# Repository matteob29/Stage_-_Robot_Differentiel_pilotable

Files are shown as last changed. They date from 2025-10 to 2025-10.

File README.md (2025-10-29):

# Stage - Robot Différentiel pilotable

Projet réalisé dans le cadre du **Stage de Première année**

**Ateliers destinés aux stagiaires de seconde**  
**ENSEIRB-MATMECA – CEA** 

**Auteurs :**  
Mattéo BINET  
Bastien TRAN-RUESCHE 

**Encadrant :**  
Thierry TARIS

**Date :** Juin 2025  

---

## Présentation générale

Cet atelier a été conçu dans le cadre du partenariat entre **l’ENSEIRB-MATMECA** et le **CEA**, dans le but d’initier des élèves de seconde aux bases de la robotique.  
Il s’est déroulé à **EirLab**, le fablab de l’enseirb, sur des séances de trois heures encadrées par des étudiants de première année.

L’objectif était de faire découvrir la démarche complète de conception d’un système embarqué à travers la réalisation d’un **robot différentiel pilotable**.  
L’atelier combine ainsi trois volets :  
1. la **découverte du robot et de ses composants** ;  
2. la **fabrication partielle du châssis** et l’assemblage ;  
3. la **programmation du comportement autonome** du robot.

---

## Le robot

<p align="center">
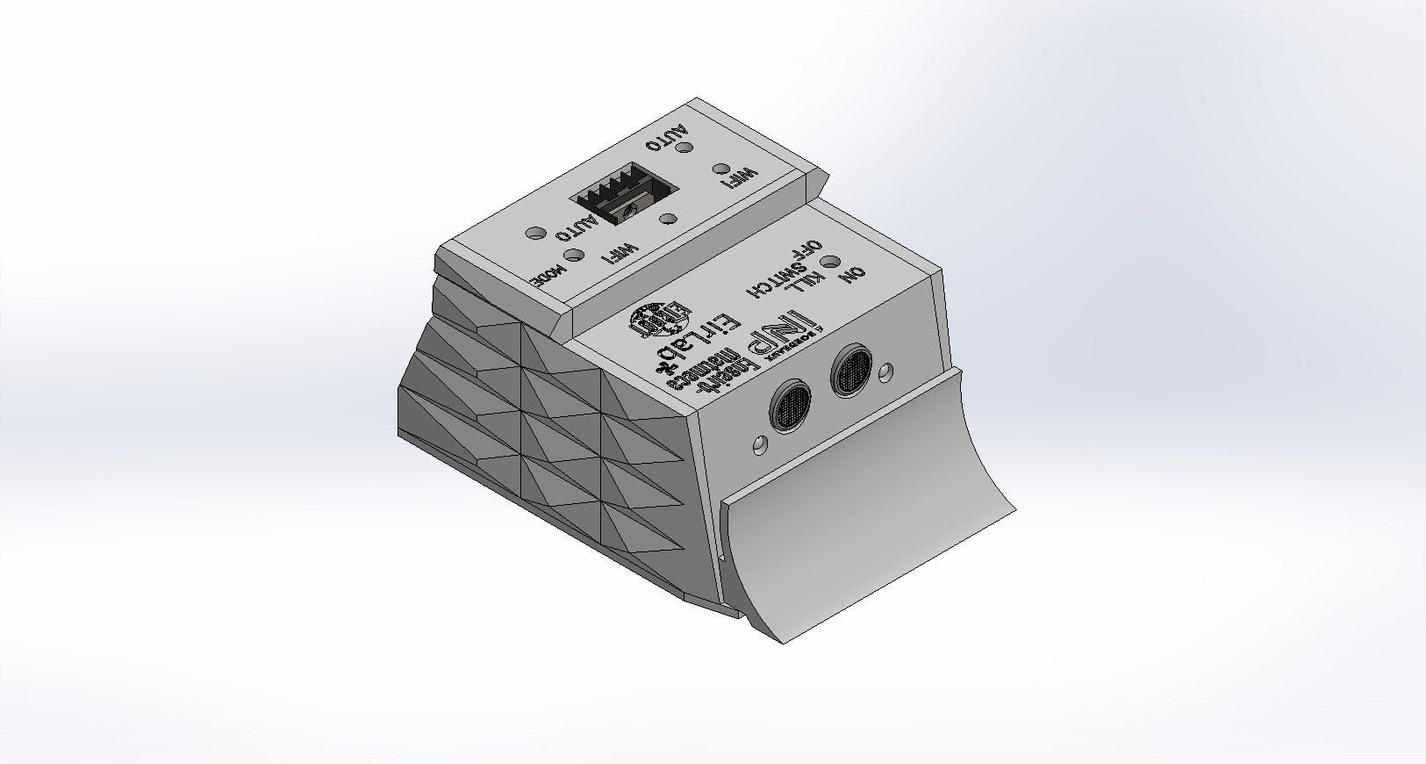
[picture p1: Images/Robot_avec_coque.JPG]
Robot avec coque
  
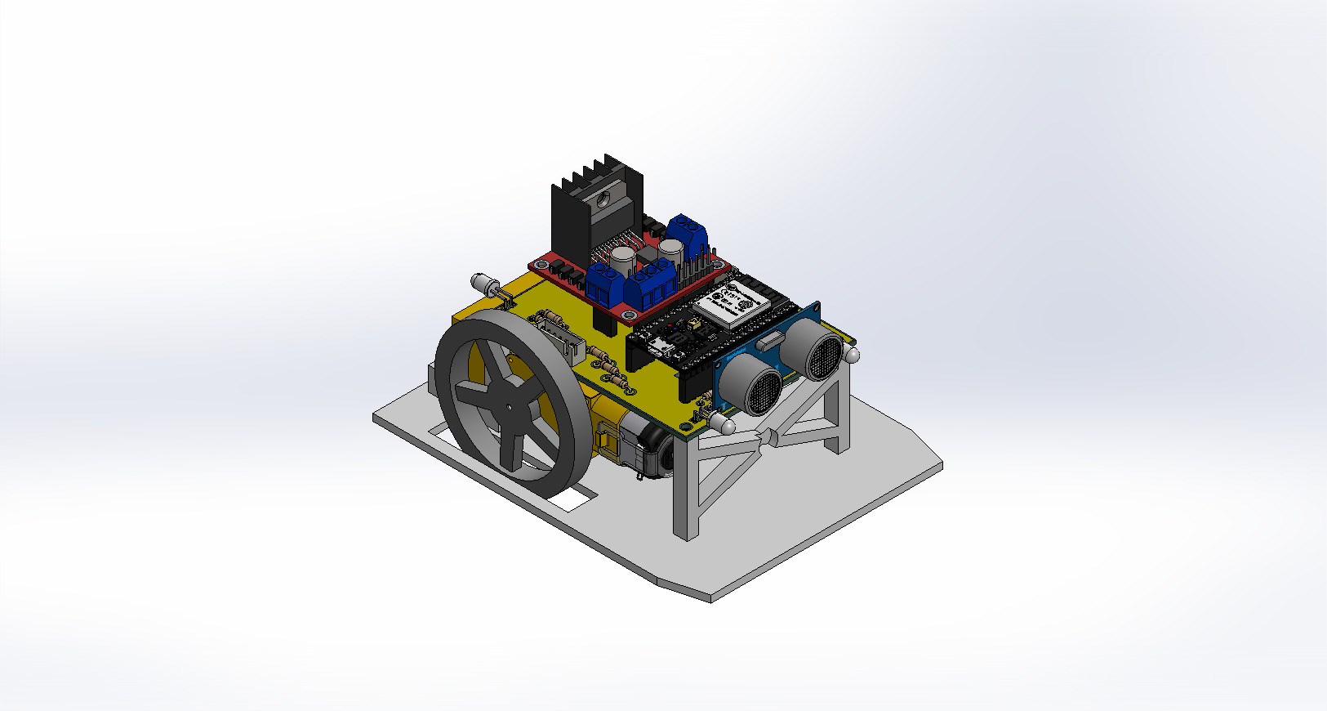
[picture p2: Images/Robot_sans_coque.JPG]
Robot sans coque
  
</p>

Le robot conçu est un **modèle différentiel** à deux roues motrices et une roue folle.  
Chaque moteur est commandé indépendamment à l’aide d’un **driver L298**, piloté par un **microcontrôleur ESP32** programmé dans l’environnement Arduino.  
L’ensemble est relié par une **carte d’interconnexion** assurant la distribution de l’alimentation et des signaux de commande.

Les principaux éléments du système sont :
- ESP32 (microcontrôleur)  
- Driver moteur L298  
- Deux moteurs à courant continu  
- Capteur à ultrasons  
- LEDs et interrupteurs  
- Batterie d’alimentation  

Le robot peut se déplacer, s’arrêter en fonction de la détection d’obstacles et être commandé à distance via une interface sans fil.

---

## Déroulement de l’atelier

L’atelier débute par une présentation du principe du robot différentiel et de ses composants électroniques.  
Les élèves réalisent ensuite la **plaque inférieure du châssis** à l’aide d’une **découpeuse laser**, puis procèdent à l’assemblage mécanique et à la soudure des moteurs.

La seconde partie est consacrée à la **programmation**.  
À partir d’un code partiellement fourni, les élèves complètent la logique du comportement autonome du robot à l’aide de fonctions simples issues d’une bibliothèque dédiée (`pami_lib.h`).

Exemples de fonctions utilisées :
- `avancer()`, `reculer()`, `stop()` : contrôle du déplacement  
- `mesurerDistance()` : lecture du capteur à ultrasons  
- `bluetoothControl()` : pilotage sans fil  

L’objectif final est d’obtenir un robot capable d’avancer, de s’arrêter en présence d’un obstacle et, en bonus, d’effectuer une manœuvre d’évitement.

---

## Objectifs pédagogiques

- Introduire les bases de la **robotique mobile** et des systèmes embarqués.  
- Apprendre à **assembler** et **câbler** un système électronique simple.  
- Découvrir la **programmation en C/Arduino** appliquée au pilotage de moteurs.  
- Développer des compétences de **rigueur, logique et travail collaboratif**.  

---

## Conclusion

Cet atelier illustre de manière concrète le processus complet de conception d’un système robotique :  
de la modélisation mécanique à la programmation, en passant par l’assemblage électronique.  
Il permet aux élèves de seconde d’aborder de façon pratique les disciplines de l’ingénierie et de découvrir le fonctionnement d’un robot autonome.

---

## Contenu du dépôt GitHub

Le dépôt [Stage - Robot Différentiel pilotable](https://github.com/matteob29/Stage_-_Robot_Differentiel_pilotable) contient les éléments suivants :

- [Codes/](./Codes)                        → Programmes ESP32 avec les controlles Wifi ou manette de PS4
- [Datasheets/](./Datasheets)                → Datasheet des coomposants utilisés
- [Images/](./Images)                      → Illustrations, photos et rendus du robot
- [Meca/](./Meca)                          → Modèles 3D et plans mécaniques (SolidWorks, SVG)
- [PCB/](./PCB)                            → Layouts et typons
- [Rapports/](./Rapports)                    → Rapports de stage et documents de présentation
- [README.md](./README.md)
  
---

© 2025 — Mattéo BINET, Bastien TRAN-RUESCHE  
Département Électronique — Stage 1ère année  
Enseirb-Matmeca — Robot Différentiel pilotable

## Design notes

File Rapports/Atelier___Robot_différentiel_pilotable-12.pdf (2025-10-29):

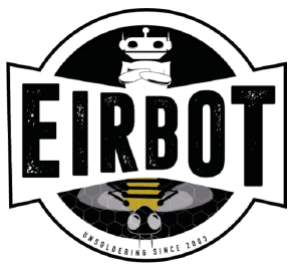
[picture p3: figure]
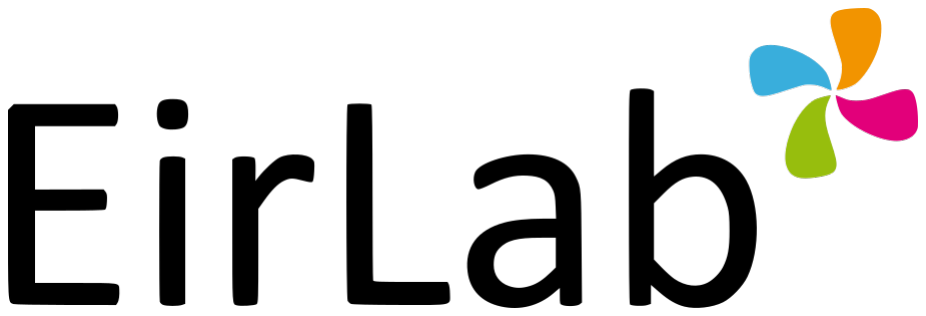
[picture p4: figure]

# Atelier - Conception d’un robot différentiel pilotable

Ateliers destinés aux stagiaires de seconde ENSEIRB-MATMECA - CEA

### Juin 2025

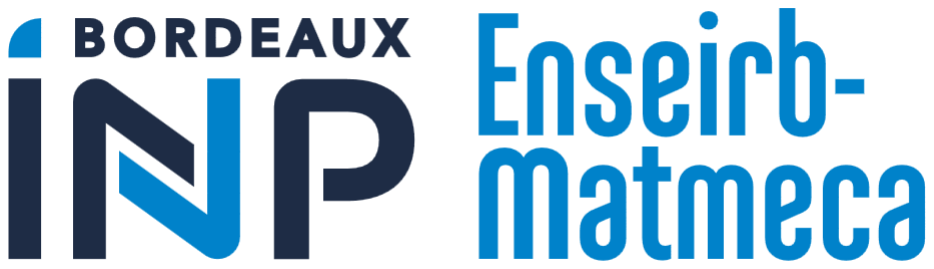
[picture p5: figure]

Auteurs :
Mattéo BINET
Bastien TRAN-RUESCHE

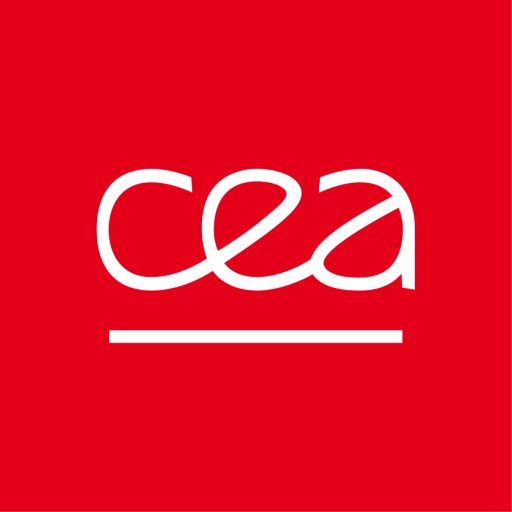
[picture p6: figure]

Tuteur :
Thierry TARIS

## Sommaire

1 Description de l’atelier | 4
2 Présentation du robot | 4
3 Partie Mécanique | 7
4 Partie Programmation | 9

2

Atelier - Conception d’un robot différentiel pilotable

## 1 Description de l’atelier

### 1.1 Format

L’atelier se déroule à EirLab (ENSEIRB-MATMECA) et dure 3 heures. Il se découpe en trois parties :
1. Présentation du robot à réaliser
2. Fabrication d’une partie du châssis à la découpeuse laser
3. Programmation du microcontrôleur

### 1.2 Cahier des charges

L’objectif de cet atelier est l’introduction à la robotique. Pour cela, les élèves de seconde participeront à plusieurs étapes de fabrication du robot. Pour gagner du temps, certaines pièces du châssis seront déjà découpées, la carte d’interconnexion préassemblée et le programme partiellement préparé.
Après la présentation du robot et de son fonctionnement, l’élève sera sollicité pour dessiner et découper la plaque de support du robot, pour assembler ce dernier (soudure et montage), ainsi que pour écrire la partie du programme correspondant au comportement « autonome » du robot.
Ainsi, un robot fonctionnel doit pouvoir être obtenu à la fin de l’atelier.

## 2 Présentation du robot

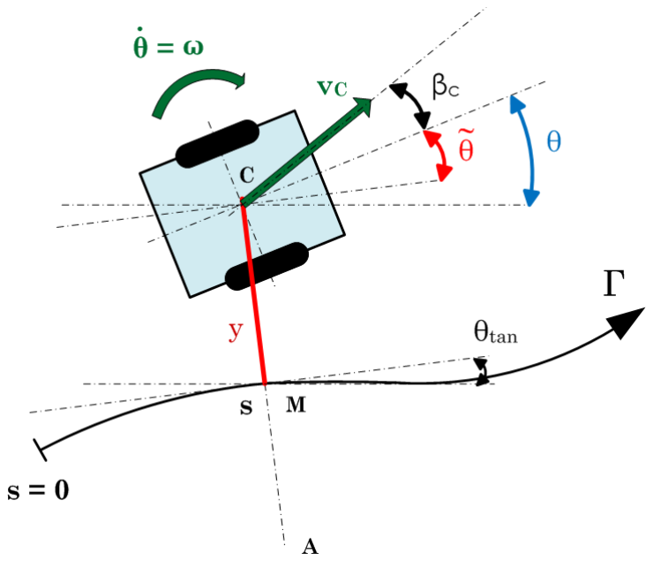
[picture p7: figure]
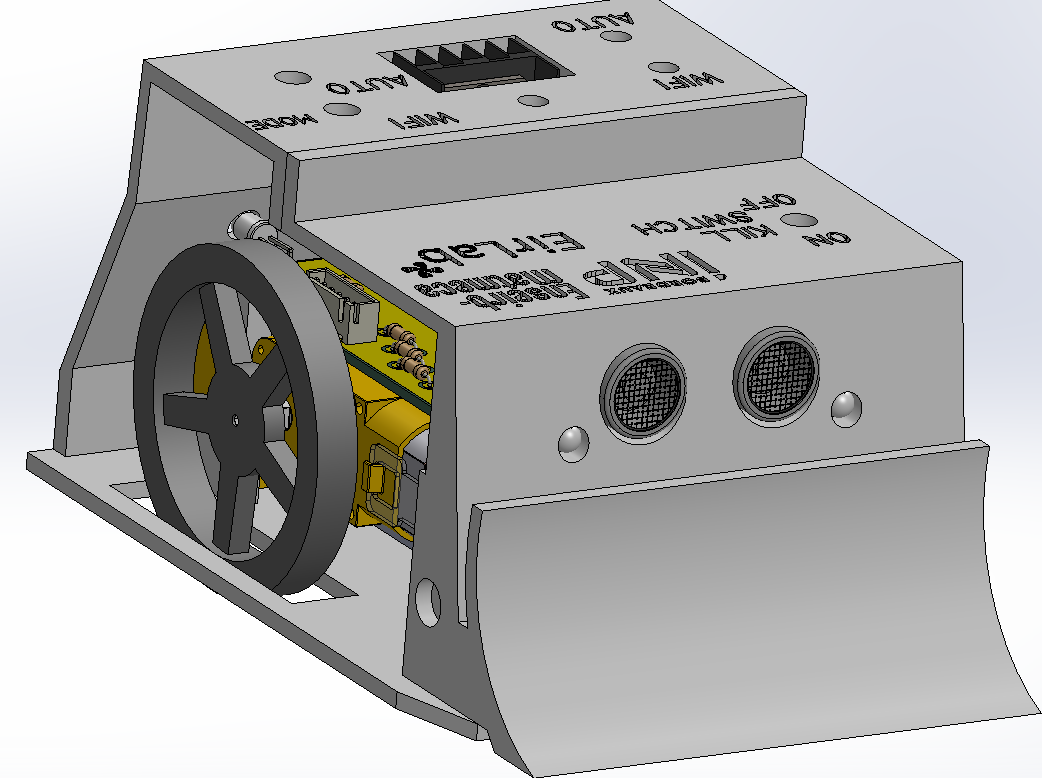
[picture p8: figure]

Le robot possède deux roues. Chaque roue est entraînée par un moteur que l’on peut contrôler de manière indépendante. Un tel robot peut effectuer plusieurs mouvements distincts :
1. Si les deux roues tournent dans le même sens et à la même vitesse, le robot va tout droit,
2. Si une des deux roues tourne plus vite, le robot tourne un peu,
3. Si les deux roues n’ont pas le même sens de rotation, le robot tourne sur lui-même.
Mattéo BINET | 4 | Bastien TRAN-RUESCHE

Cela veut dire que pour faire se mouvoir le robot comme on le veut, il faut contrôler le sens et la vitesse de la rotation de chaque moteur.

Le contrôle des moteurs est réalisé à l’aide : d’un microcontrôleur et d’un driver de moteur.

### 2.1 Les moteurs DC

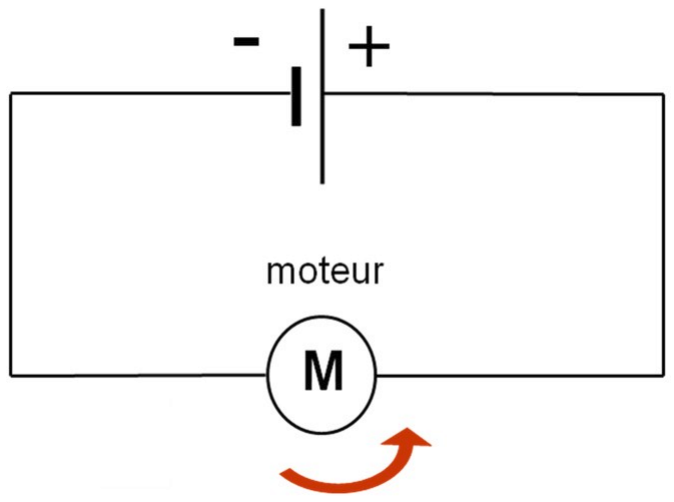
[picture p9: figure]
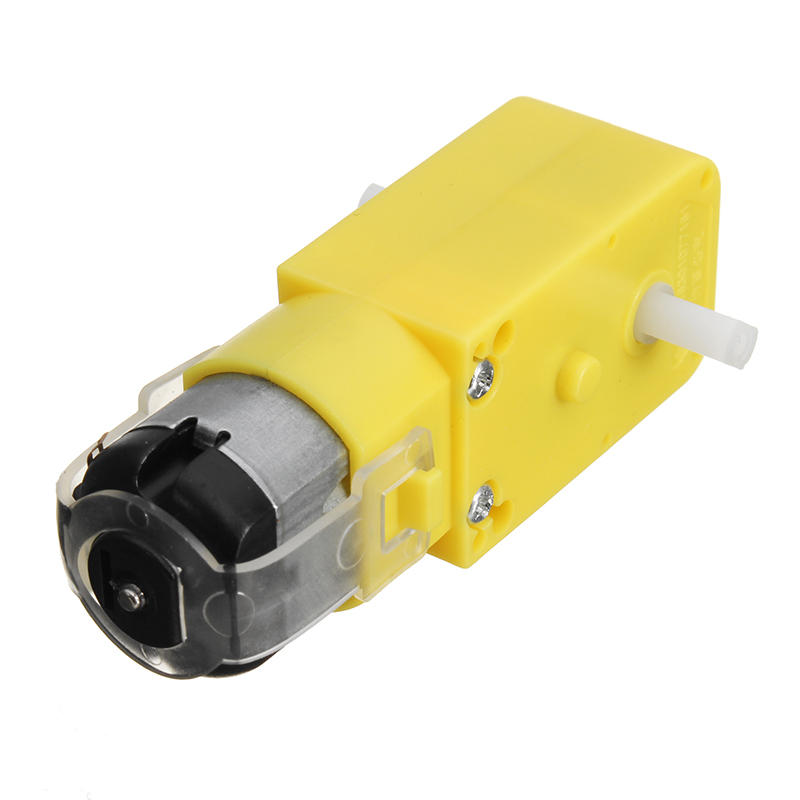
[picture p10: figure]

(a) Moteur DC | (b) Schéma électrique de branchement moteur

Direct Current = Courant Continu
Un moteur à courant continu est facilement contrôlable. Il suffit de le faire traverser par un courant (en appliquant une tension à ses bornes). En fonction de l’intensité et du sens du courant, il est possible de contrôler la vitesse et le sens de la rotation.

### 2.2 Le driver du moteur

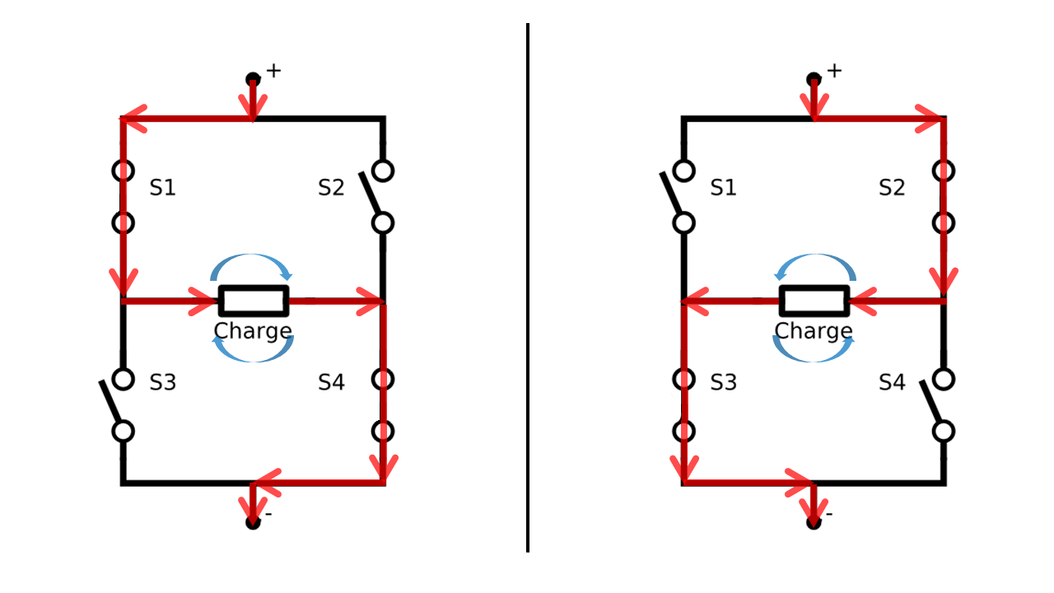
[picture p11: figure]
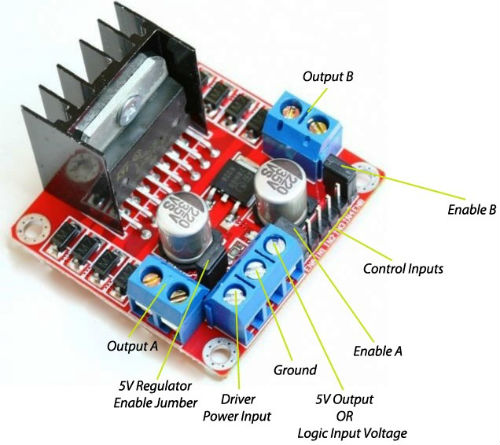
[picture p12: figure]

(a) Driver L298 | | (b) Schéma électrique du pont en H

Pour fournir la tension contrôlée aux moteurs (≈ 12V ), un composant de puissance est nécessaire car l’Arduino ne fournit pas une tension suffisante (≈ 5V ). Ce composant est appelé « driver » (peut se traduire par entraîneur).

La référence utilisée est le pont en H L298. Sans entrer dans les détails, il est commandé par un signal analogique donné par l’Arduino (entre 0 et 5V), et fournit aux moteurs une

Mattéo BINET | 5 | Bastien TRAN-RUESCHE

tension proportionnelle à ce signal.

Le driver permet ainsi de commander les moteurs de manière précise, mais avec puissance.

### 2.3 Le microcontrôleur (Arduino)

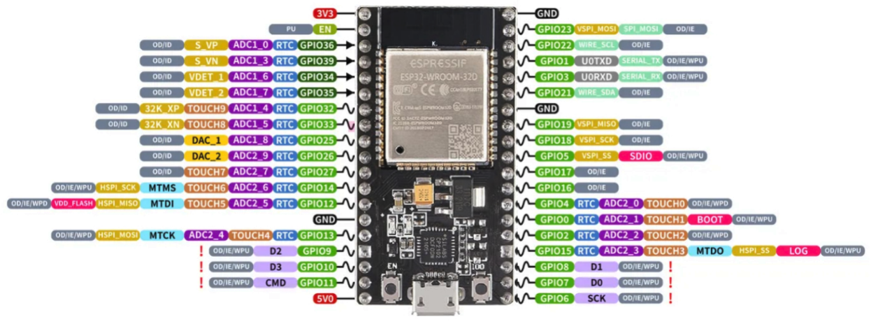
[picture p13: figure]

(a) Broches de l’ESP32

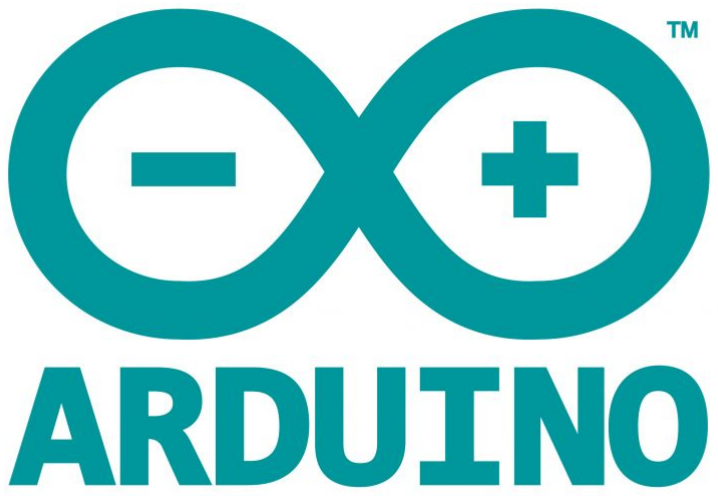
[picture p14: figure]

Un microcontrôleur est une carte programmable. En fonction du code qu’on lui donne, elle peut lire ou appliquer des tensions à ses bornes au cours du temps.

La carte utilisée est une ESP32, mais elle possède le même comportement qu’une carte Arduino (plus répandue et plus documentée).
Son rôle dans le robot est :
1. La mesure des entrées comme les boutons, le capteur à ultrasons...
2. Le choix des actions à réaliser en fonction de l’état des entrées
3. L’application des signaux de contrôle à ses sorties, vers le driver et les lumières par exemple.
Toutes ces étapes doivent être rigoureusement définies dans le programme donné au préalable au microcontrôleur. Si on a l’impression que le robot est autonome, c’est parce que son code est bien réalisé.

### 2.4 La carte d’interconnexion

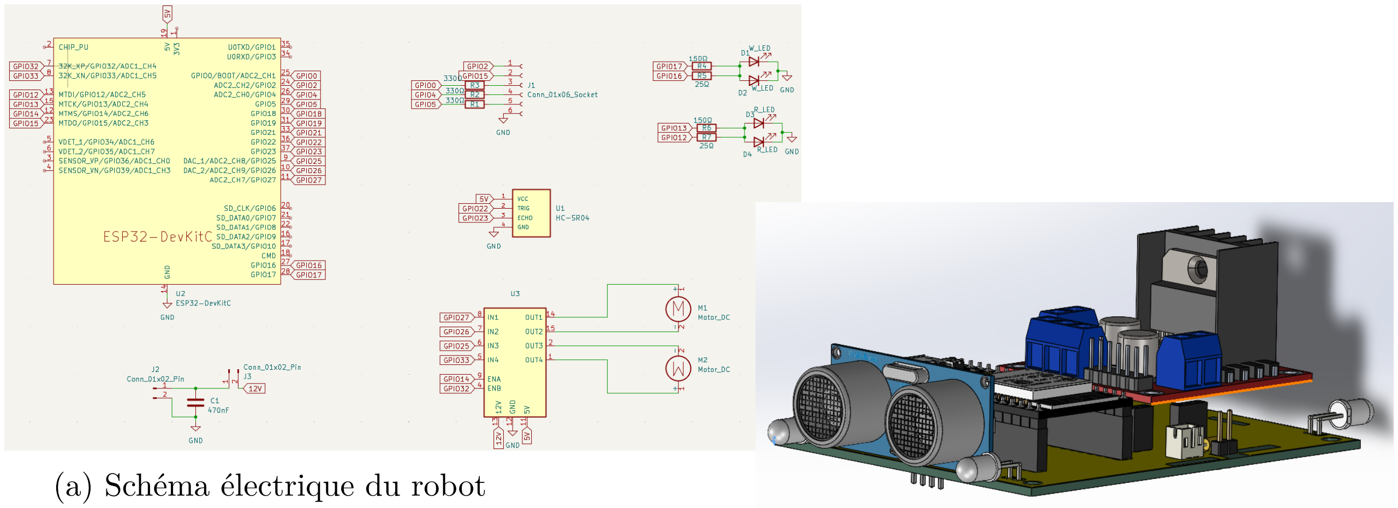
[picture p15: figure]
(a) Schéma électrique du robot

Mattéo BINET | 6 | Bastien TRAN-RUESCHE

Pour ce projet, une carte électronique a été préparée. Elle sert à relier les différents composants entre eux. Par exemple, six broches de l’ESP32 sont reliées aux six entrées de contrôle du driver. De manière similaire, l’alimentation 5V est partagée entre le capteur à ultrasons, la carte Arduino et le driver...
Les composants électroniques du robot sont :
1. le microcontrôleur ESP32,
2. les interrupteurs (3),
3. les lumières (7),
4. le capteur à ultrasons,
5. le driver moteur,
6. les moteurs (2),
7. la prise pour la batterie

## 3 Partie Mécanique

### 3.1 Objectif

La partie mécanique doit permettre aux stagiaires de fabriquer une partie du châssis du robot (la plaque inférieure) et de souder les moteurs à la carte d’interconnexion. Ils seront aussi amenés à assembler certaines parties du robot.

### 3.2 Fabrication de la plaque

Le logiciel utilisé n’importe pas beaucoup. Le seul point important est que le dessin final doit pouvoir être obtenu au format .svg .
Le dessin de la carte se fait suivant les cotes suivantes :
Considérations lors du dessin :

— Ne déssiner que la moitiée de la plaque. L’autre moitée s’obtient par symétrie,
— Placer les trous d’un même élement (supports moteurs, supports carte, trous des roues...) les un par rapport aux autres
— Placer les différents éléments par rapport à une même référence. On peut choisir la ligne de derrière et une ligne du côté (il faut donc les placer en premier).
Mattéo BINET | 7 | Bastien TRAN-RUESCHE

### 3.3 Soudure

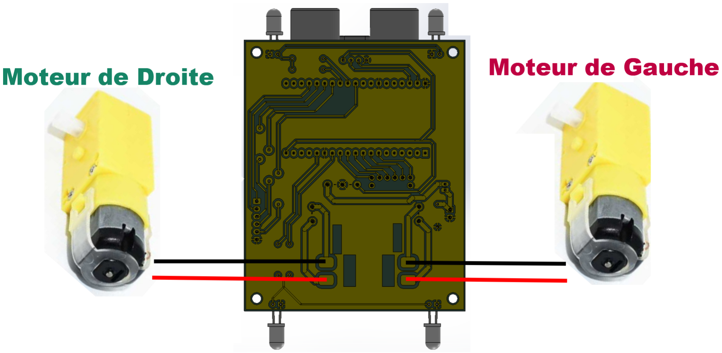
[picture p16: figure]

Figure 8 – Schéma de câblage des moteurs

Il faut relier les moteurs à la carte d’interconnexion. Chaque moteur possède deux fils : il y a donc 4 fils à souder sur la carte.

/!\ Pour la sécurité /!\ (gardez vos mains et vos yeux fonctionnels)

1. Porter des lunettes de sécurité
2. Souder sous supervision mais seul sur la table
3. Soit vous utilisez activement le fer, soit il est rangé dans son socle
4. Lors de la soudure, garder le fer loin des surfaces en plastiques et de votre autre main.
5. Les surfaces sont encore brulantes pendant plusieures minutes
6. Les troisièmes mains sont ajustables. Pas besoin de se mettre dans des positions incomfortables et dangeureuses.

Conseil pour une soudure de compétition :
— régler son fer entre 350° et 380°.
— nétoyr puis étamer son fer à chaque utilisation
— étamer les deux surfaces individuellement. Ensuite, réunir les deux surfaces ainsi que le fer. Il faut bien attendre que tout l’étain soit fondu avant d’enlever le fer. — L’étain ne se solidifie pas instantanément, il faut garder les surfaces à souder immobiles.
— Ne pas inverser + et - ; ne pas iverser moteur droit et moteur gauche.
Mattéo BINET | 8 | Bastien TRAN-RUESCHE

## 4 Partie Programmation

### 4.1 Objectif

L’objectif de la partie programmation est que le stagiaire programme le comportement autonome du robot.
La partie contrôle avec son téléphone à distance ainsi que les fonctions pour le déplacement du robot (avancer, aller à droite...) sont déjà programmées. Le stagiaire pourra les utiliser.

Des aides à la programmation sont aussi données plus loin dans le document.

### 4.2 Etapes de programmation

Dans cette partie, le stagiaire doit programmer le robot. Vu le temps accordé à l’atelier, une partie du code est déjà réalisée.

Documents fournis par les encadrants :
1. La librairie pami_lib.h du robot. On y trouve les fonctions pour faire bouger le robot comme avancer, reculer...
2. Le code main.c prérempli. L’import des librairies, la définition des pins et la fonction setup() sont déjà réalisés.

Travail demandé au stagiaire :
1. Réaliser la fonction loop(). Le comportement attendu est décrit ci-dessous dans les différentes étapes.

### 4.2.1 Étape 1 - Faire avancer le robot

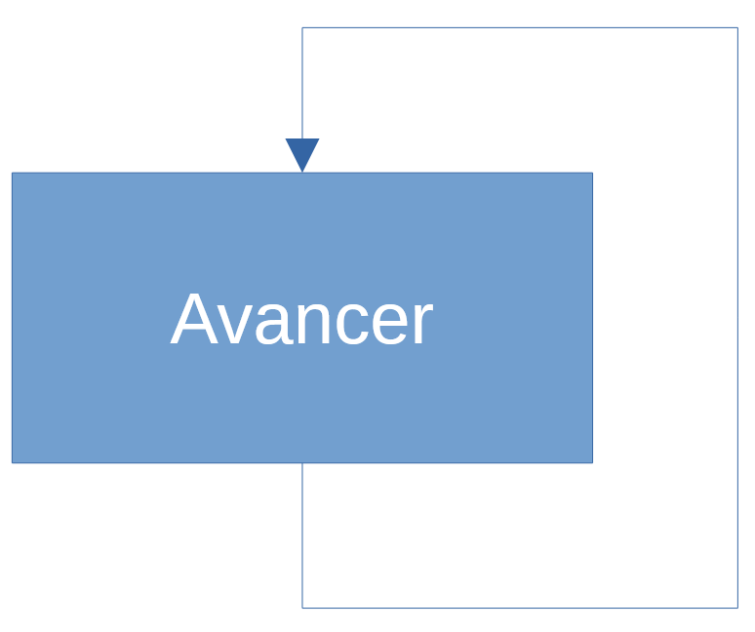
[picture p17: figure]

Pour faire avancer le robot, il faut appeler la fonction avancer(). On peut dire 3 choses sur cette fonction :
1. Elle est non bloquante. Son exécution est rapide et permet au programme de continuer à défiler. (contre-exemple : delay()).
2. Elle change l’état du robot. Tant qu’une instruction contraire n’est pas donnée, le robot continue à avancer.
3. L’appeler une seconde fois ne change rien.
À faire : Dans la loop(), écrire l’instruction avancer(); . Ensuite, téléverser.
Mattéo BINET | 9 | Bastien TRAN-RUESCHE

### 4.2.2 Étape 2 - Faire arrêter le robot

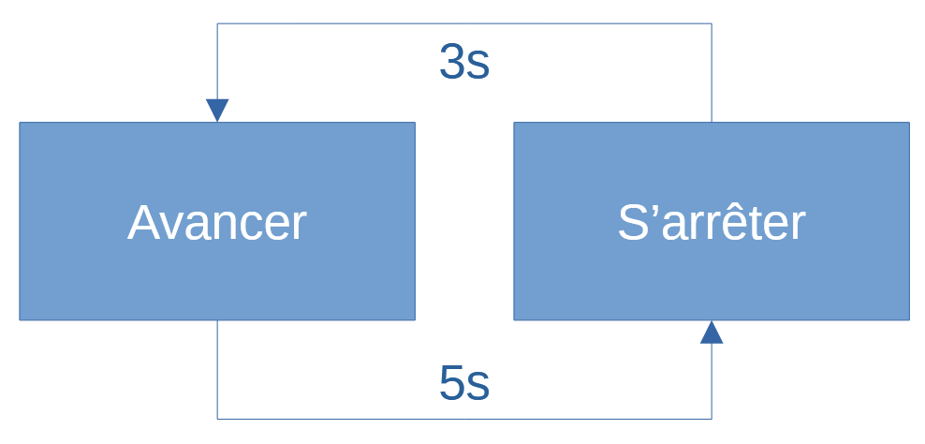
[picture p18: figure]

L’objectif est de faire avancer et arrêter le robot. La fonction d’attente est delay(). La fonction d’arrêt est stop().
Quelques précisions sur la fonction delay() :
1. Elle est bloquante. Son appel va stopper la lecture du programme pendant la durée spécifiée.
2. Aucun changement n’est effectué. Si le robot avance avant l’appel de delay(), il continuera d’avancer pendant toute la durée d’attente.

À faire : Modifier le programme pour que le robot : avance pendant 5 secondes, s’arrête pendant 3 secondes, et recommence en boucle...

### 4.2.3 Étape 3 - Utiliser le capteur à ultrasons

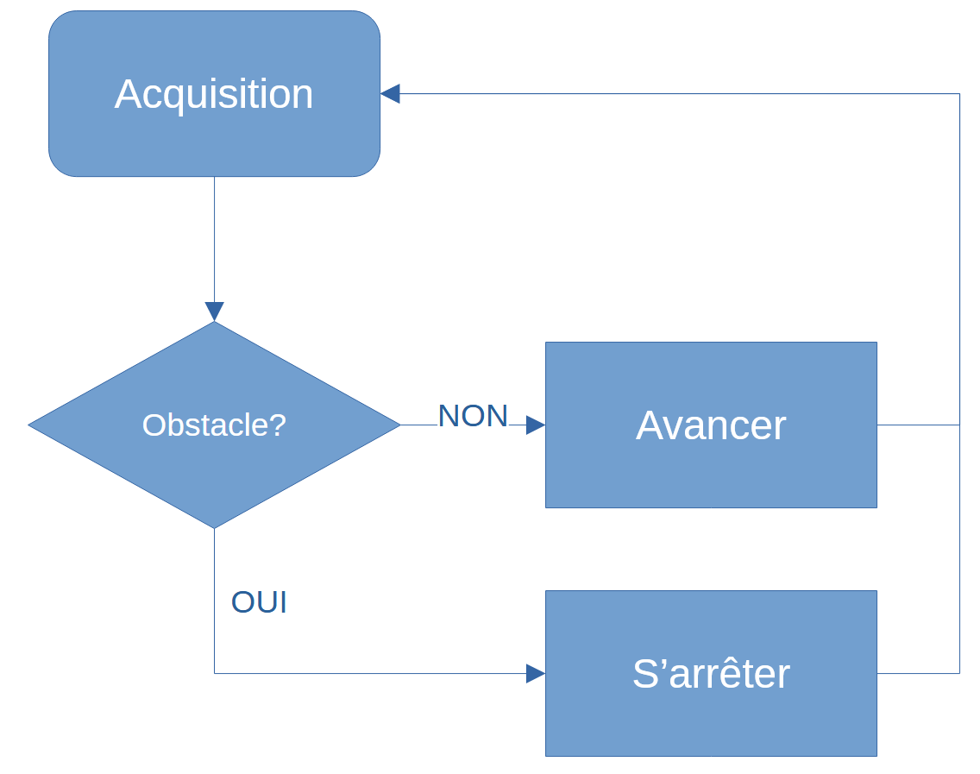
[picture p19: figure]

La fonction mesurerDistance() renvoie la distance en cm devant le capteur. On veut que le robot s’arrête quand il voit un obstacle devant lui. Il faut donc :
1. Récupérer la distance mesurée
2. La comparer à une valeur de référence (15 cm par exemple)
3. Choisir s’il faut avancer ou s’arrêter
À faire : Écrire dans la loop() un programme qui fait avancer le robot tant qu’un obstacle n’est pas détecté.
Mattéo BINET | 10 | Bastien TRAN-RUESCHE

### 4.2.4 Étape 4 - Manœuvre d’évitement (Bonus)

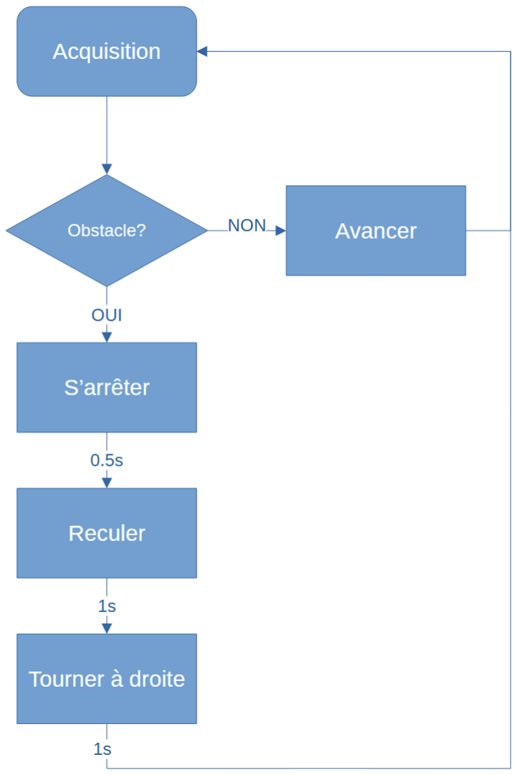
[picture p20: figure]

On propose maintenant en bonus d’effectuer une manœuvre d’évitement par le robot pour ne pas qu’il reste bloqué.

Bonus : Modifier le programme pour que le robot change de direction quand il détecte un obstacle.

### 4.3 Aides à la programmation

### 4.3.1 Variables et fonctions

— int a = 3; : entier
— float b = 3.14; : nombre décimal
— b = a + b; : modification de variable
— maFonction(3); : appel de fonction
— float c = maFonction(a); : affectation du résultat d’une fonction

/!\ Il faut mettre des points-virgules pour signaler la fin de l’instruction. Exemple :

int a = 3;

### 4.3.2 Conditions et boucles

Les tests : a == b, a < b, a <= b, a > b, a == HIGH...
Les boucles :

— if(condition){ instruction1; instruction2; ... } : si
— if(condition){ } else{ } : si ... sinon

— if(condition){ } else if(condition2){ } else{ } : si ... sinon si ... sinon

Mattéo BINET | 11 | Bastien TRAN-RUESCHE

— while(condition){ } : tant que

— for(initialisation; condition; incrment){ } : pour

### 4.3.3 Fonctions propres à Arduino

— setup() : fonction automatiquement appelée au démarrage de la carte — loop() : fonction automatiquement appelée en boucle
— pinMode(pin, mode); : fonction pour configurer une broche
— digitalRead(pin); : fonction pour lire la valeur d’une broche. Renvoie LOW ou HIGH — digitalWrite(pin, value); : fonction pour écrire LOW ou HIGH sur une broche

Les fonctions setup() et loop() sont appelées automatiquement par la carte Arduino. Elles doivent être définies par l’utilisateur avec le type void, car elles ne renvoient rien. Exemple : void setup(){ ... }. On utilise la même structure pour définir ses propres fonctions.
En revanche, les fonctions comme pinMode sont déjà définies ailleurs. L’utilisateur peut les appeler s’il le souhaite.
/!\ Il faut mettre des points-virgules pour signaler la fin de l’instruction. Exemple :

pinMode(12, INPUT);

### 4.3.4 Fonctions de la librairie PAMI

— beginPami(); : initialise le PAMI
— avancer(); : pour avancer
— reculer(); : pour reculer
— droite(); : le PAMI tourne sur lui-même (sens horaire)
— gauche(); : le PAMI tourne sur lui-même (sens antihoraire)
— stop(); : pour s’arrêter
— mesurerDistance(); : retourne la distance en cm mesurée par le capteur à ultrasons — bluetoothControl(); : actualise le comportement du robot en fonction des commandes Bluetooth

/!\ Il faut mettre des points-virgules pour signaler la fin de l’instruction. Exemple :

avancer();

### 4.3.5 Autres

— Attente en ms : delay(ms_a_attendre);

— Commentaire : // reste de la ligne en commentaire
— Inclure une librairie : #include "nomLibrairie.h"

— Macro : #define MA_MACRO 12

Mattéo BINET | 12 | Bastien TRAN-RUESCHE

### 4.3.6 Un exemple pour illustrer

Le programme suivant scrute l’interrupteur sur la broche 13. S’il est activé, alors c’est le capteur à ultrasons qui est scruté. Si la distance devant le capteur est supérieure à 15 cm, alors le robot avance. Si une des deux conditions n’est pas remplie, le robot est arrêté.

Listing 1 – Exemple C++

# include " pami_lib .h"

# define SWITCH_PIN 13

void setup () {
beginPami () ;
pinMode ( SWITCH_PIN , INPUT ) ;

}

void loop () {
if( digitalRead ( SWITCH_PIN ) == HIGH ) { int distance = mesurerDistance () ; if( distance >= 15) {
avancer () ;
} else {
stop () ;

}

}
else {
stop () ;

}

}

Mattéo BINET | 13 | Bastien TRAN-RUESCHE

E E

F F

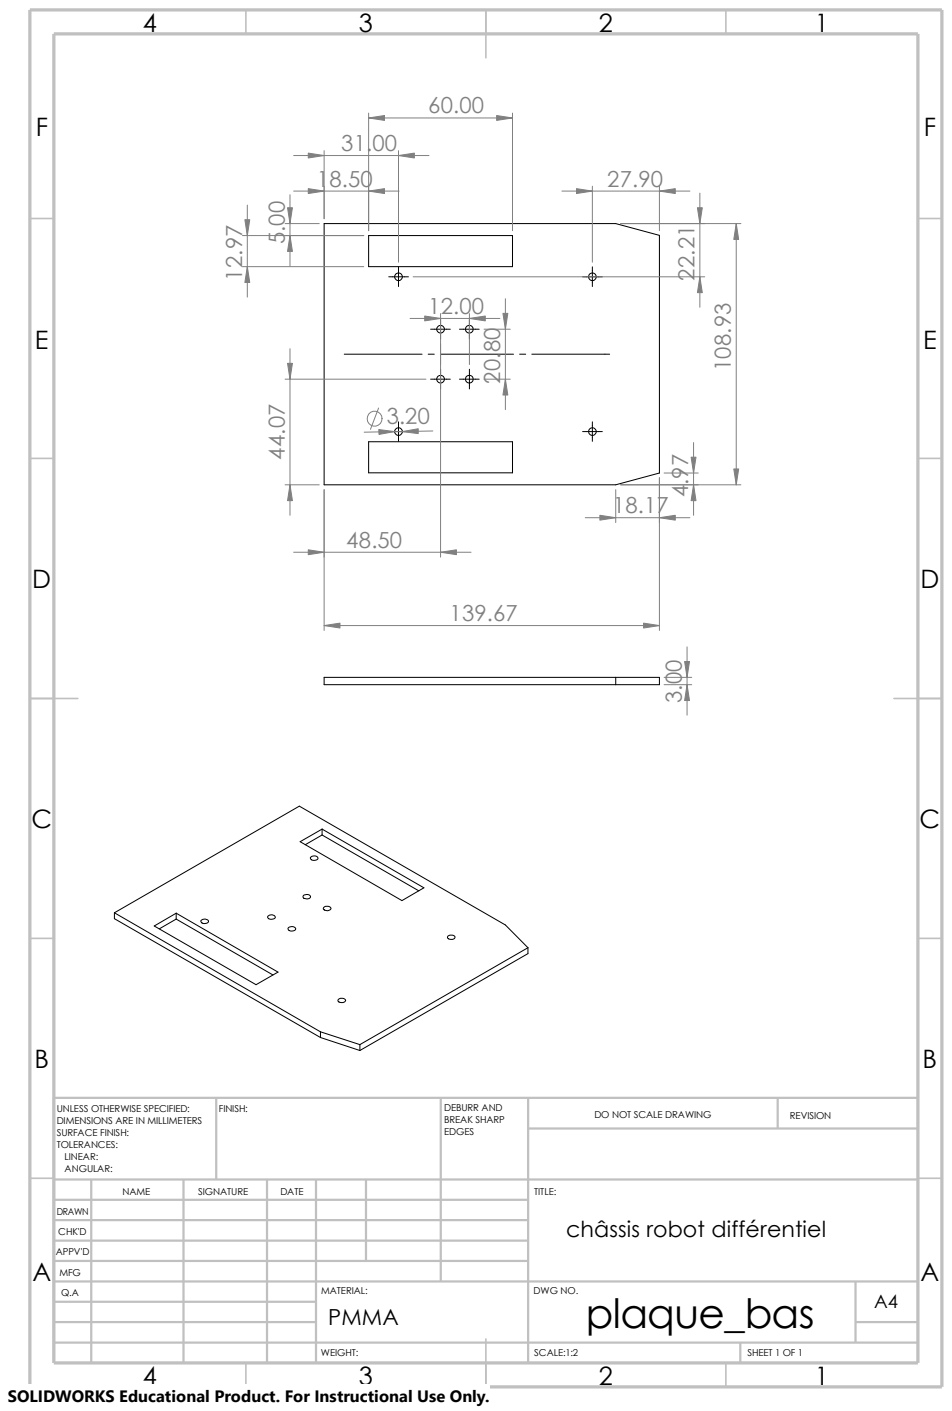
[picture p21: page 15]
DWG NO.; SCALE:1:2; TITLE:; WEIGHT:; SHEET 1 OF 1; DO NOT SCALE DRAWING; REVISION; MATERIAL:; SIGNATURE; DATE DRAWN; MFG; FINISH:; EDGES; NAME; DEBURR AND BREAK SHARP; plaque_bas ³.00; PMMA; châssis robot différentiel ¹⁰⁸.93 44.07

UNLESS OTHERWISE SPECIFIED:
DIMENSIONS ARE IN MILLIMETERS
SURFACE FINISH:
TOLERANCES:
LINEAR:
ANGULAR:

CHK'D
APPV'D

SOLIDWORKS Educational Product. For Instructional Use Only.

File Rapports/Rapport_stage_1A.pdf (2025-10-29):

# LE RÉCIT DES DÉCOUVERTES

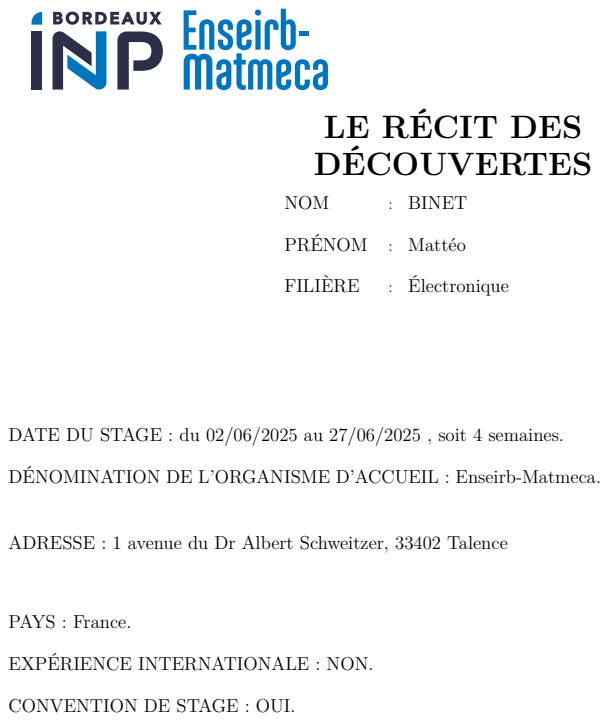
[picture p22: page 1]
NOM; : BINET; PRÉNOM; : Mattéo; FILIÈRE; : Électronique; PAYS : France.

DATE DU STAGE : du 02/06/2025 au 27/06/2025 , soit 4 semaines.

DÉNOMINATION DE L’ORGANISME D’ACCUEIL : Enseirb-Matmeca.

ADRESSE : 1 avenue du Dr Albert Schweitzer, 33402 Talence

EXPÉRIENCE INTERNATIONALE : NON.

CONVENTION DE STAGE : OUI.

## Sommaire

1 Introduction | 4
2 Récit de la découverte | 6

LE RÉCIT DES DÉCOUVERTES

## 1 Introduction

### 1.1 Choix du stage

Lorsque j’ai recherché un stage pour la fin de ma première année, je voulais une expérience en lien avec mes études d’électronique. Mon objectif était de mettre en pratique certaines notions abordées en cours, comme la réalisation de cartes électroniques, la programmation en C/C++ ou l’utilisation de microcontrôleurs.
J’espérais également pouvoir associer à ce travail certaines de mes passions personnelles, notamment la modélisation 3D. C’est ce qui m’a immédiatement attiré dans le projet de fabrication d’un petit robot : il combinait la conception d’un objet concret et la transmission de cette expérience à des lycéens dans un cadre pédagogique.
La durée du stage, fixée à quatre semaines, s’adaptait parfaitement à ce format, avec deux semaines consacrées à la réalisation du robot et deux autres à l’animation d’ateliers.

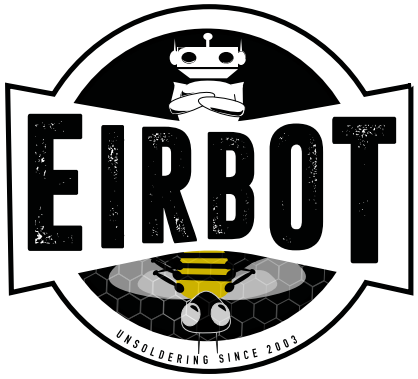
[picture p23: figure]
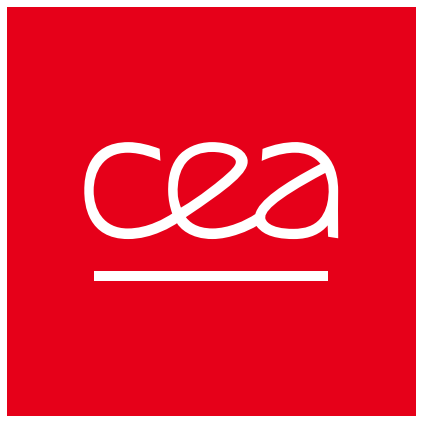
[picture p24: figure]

Figure 1 – Entités intervenantes dans le stage

Mattéo BINET | 4

### 1.2 Présentation du lieu de stage et du contexte

Mon stage s’est déroulé au sein d’EirLab, le fablab de l’ENSEIRB-MATMECA. Cet espace de 400 m² est dédié à la fabrication numérique et met à disposition des imprimantes 3D, une découpeuse laser, une fraiseuse CNC ainsi que du matériel électronique. L’école avait choisi de recruter des étudiants de première année pour préparer des ateliers destinés à des lycéens, en partenariat avec le CEA. Ce projet s’inscrivait pleinement dans l’esprit collaboratif d’EirLab.
J’ai participé à ce stage en tant que membre de l’association EirLab, aux côtés de mon binôme, M. Bastien Tran-Ruesche, de l’association de robotique EirBot. Notre mission était encadrée par M. Thierry Taris, ancien responsable de la filière Électronique, et accompagnée par les présidents des deux associations, M. Quentin Fallito (EirLab) et M. Romain Goudeau (EirBot).

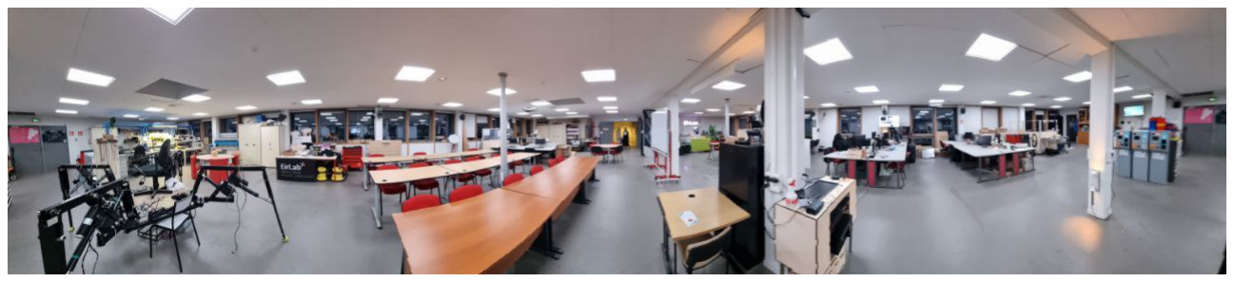
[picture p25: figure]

Figure 2 – Plateau ouvert d’EirLab

Au-delà du cadre immédiat de l’EirLab, ce stage s’inscrivait dans un dispositif plus large porté conjointement par l’ENSEIRB-MATMECA et le CEA. Ces deux institutions proposaient à des élèves de seconde une série d’ateliers de découverte scientifique et technique, couvrant des thématiques variées telles que la robotique, la bioélectronique, l’optique ou encore la cryptographie. Huit ateliers étaient organisés par notre école, chacun encadré par des groupes d’étudiants, tandis que onze autres, dont une visite du Laser Mégajoule, étaient proposés par le CEA. L’objectif de ce programme était de donner aux lycéens un premier aperçu concret de la diversité des métiers de l’ingénierie et de la recherche. C’est dans ce contexte que s’inscrivait notre stage : concevoir et préparer l’atelier de robotique, destiné à des binômes d’élèves de seconde, sur des sessions de trois heures.

## 2 Récit de la découverte

### 2.1 Création du robot

Les deux premières semaines du stage ont été consacrées à la préparation de l’atelier. En amont, une réunion a été organisée avec les stagiaires, notre tuteur et les présidents des associations afin de commencer à visualiser les grandes lignes du projet. Une seconde réunion, le premier jour de stage, a permis de définir plus précisément les objectifs à atteindre et de planifier le travail à réaliser pour que tout soit prêt à la troisième semaine. Il fallait absolument que le stage soit prêt pour les stagiaires de seconde.
Avec mon binôme, nous avons ensuite choisi les outils que nous allions utiliser : un logiciel de conception mécanique pour la modélisation en trois dimensions (SolidWorks), un autre pour la réalisation des circuits électroniques (Kicad), ainsi qu’un environnement de programmation pour écrire le code du robot (VSCode).
Nous avons également défini les composants nécessaires au projet, comme le microcontrôleur, les moteurs et leurs systèmes de commande. L’idée était de concevoir un robot simple à construire, mais qui puisse aussi servir de base à de futurs projets pour d’autres étudiants.
À titre d’exemple, une journée type durant cette période commençait à 9h et on débutait par se mettre d’accord pour répartir les tâches de la journée. L’un pouvait avancer sur la modélisation du châssis tandis que l’autre travaillait sur la préparation du circuit électronique. Puis à midi, nous allions manger au Restaurant Universitaire afin de faire une pause et de prendre du recule sur nos décisions de conception. Puis on reprenait vers 14h souvent sur une autre partie que celle faite le matin même. L’après-midi était généralement consacré à des essais pratiques et de la production de pièce (Carte électronique, découpe laser ou impression 3D).


Figure 3 – Modélisation du Robot sur SolidWorks avec coque


Figure 4 – Modélisation du Robot sur SolidWorks sans coque

Un autre travail essentiel a consisté à la fin de la deuxième semaine, à préparer le contenu du stage destiné aux lycéens. Plusieurs ateliers ont été retenus pour occuper une séance de trois heures : modéliser le châssis du robot, le découper et le graver au laser, souder les éléments électroniques, faire le montage du robot, puis programmer et tester le robot pour un mode de fonctionnement automatique. Afin de rendre l’expérience plus motivante, chaque élève pouvait personnaliser son châssis en y gravant une image de son choix, ce qui a donné lieu à des résultats variés et originaux. Enfin, une fois toutes ces étapes réalisées, les participants avaient la possibilité de piloter le robot à distance avec leur téléphone, grâce à la connexion sans fil (Wi-Fi).
Le point le plus délicat, au cours de cette préparation, a été d’évaluer les connaissances et la capacité d’attention de lycéens de seconde. Il fallait trouver un équilibre entre un contenu suffisamment intéressant et des activités accessibles à leur niveau. C’est pour cette raison que nous avons prévu plusieurs ateliers différents, afin d’éviter la répétition et de pouvoir alterner les rôles avec mon binôme.

### 2.2 Mise en œuvre des ateliers

Les deux dernières semaines du stage ont été consacrées à l’accueil et à l’encadrement des élèves de seconde. Chaque binôme disposait d’une séance de trois heures avec nous. Notre rôle était de guider les élèves à travers les différentes étapes en leur donnant des explications simples et adaptées à leur niveau. L’objectif était de leur permettre de comprendre les grandes lignes de la démarche tout en conservant un aspect concret et ludique. Lorsque nous devions expliquer un concept ou le fonctionnement d’un élément technique, il était souvent nécessaire de faire le lien avec quelque chose qu’ils connaissaient déjà et de simplifier au maximum les explications.
Un moment particulièrement apprécié fut la personnalisation du châssis grâce à la gravure laser, qui donnait lieu à des résultats variés et parfois très créatifs. Chaque élève repartait avec son propre châssis personnalisé : certains choisissaient une image du Laser Mégajoule, d’autres représentaient une vague en référence à un autre atelier suivi auparavant.
L’encadrement de ces ateliers représentait une expérience nouvelle et exigeante. Il fallait s’adapter au rythme de chaque binôme, répondre à des questions parfois complexe et gérer le temps de manière stricte afin que toutes les étapes puissent être réalisées dans la limite des trois heures. Avec mon binôme, nous nous relayions pour assurer un suivi attentif et maintenir l’intérêt des élèves tout au long de la séance.

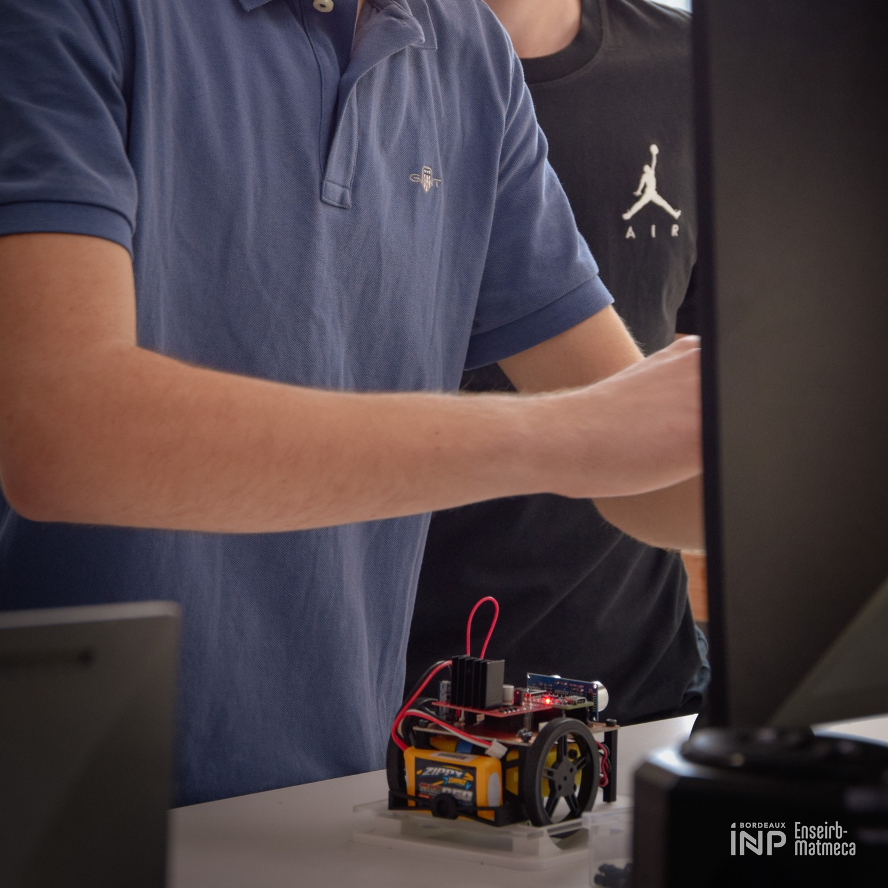
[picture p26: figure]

Figure 5 – Photos montrant le montage du robot et la conception du châssis.
Source : Instagram : enseirbmatmeca.bxinp

Ce qui m’a particulièrement marqué est la capacité des élèves à réussir les activités, même lorsqu’elles constituaient pour eux une découverte complète. Leur curiosité et leur envie d’apprendre leur permettaient de dépasser rapidement les premières difficultés, et ils prenaient visiblement plaisir à manipuler le matériel et à explorer de nouvelles notions. De mon côté, j’ai découvert l’importance d’adapter mon discours à un public plus jeune, en simplifiant le vocabulaire et en prenant le temps de reformuler lorsque cela était nécessaire. J’ai également mesuré à quel point la préparation en amont avait été déterminante : elle nous a permis de gérer les imprévus avec souplesse et d’assurer le bon déroulement des séances. Par exemple, lorsque la découpeuse laser était déjà utilisée, nous pouvions proposer immédiatement une autre activité, comme la soudure, et ainsi maintenir le rythme de l’atelier.
Cette expérience m’a donc apporté autant sur le plan technique que sur le plan humain, en développant ma capacité à transmettre, à encadrer et à m’adapter aux situations.

## Conclusion

Ce stage m’a permis de vivre une expérience riche et variée, à la fois technique et humaine. J’ai été marqué par l’équilibre entre la phase de préparation, où il fallait faire preuve de méthode et d’organisation, et la phase d’animation, où l’adaptation et la pédagogie étaient essentielles.
Parmi les aspects les plus marquants, je retiens la curiosité et l’enthousiasme des élèves, qui ont su réussir des activités nouvelles pour eux avec beaucoup d’implication. Leur motivation a rendu l’encadrement stimulant et gratifiant. J’ai également découvert l’importance de la simplification du discours et de la capacité à trouver des exemples concrets pour expliquer un concept complexe.
Certaines difficultés ont tout de même jalonné le stage, notamment la nécessité de gérer le temps limité des ateliers et de s’adapter aux imprévus techniques ou organisationnels. Toutefois, ces contraintes se sont révélées formatrices, car elles m’ont appris à faire preuve de souplesse et à maintenir un déroulement cohérent malgré les aléas.
En définitive, cette découverte a renforcé mon intérêt pour l’électronique et la robotique, tout en m’ouvrant à une dimension nouvelle : la transmission et l’encadrement. Elle m’a montré que le métier d’ingénieur ne se limite pas à des compétences techniques, mais implique aussi de savoir communiquer, accompagner et vulgariser son savoir. Cette expérience s’inscrit donc pleinement dans mon projet de formation, et constitue une étape précieuse dans mon parcours.

# ATTESTATION D’ACTIVITE

### Remettre l’original avec le rapport de stage

### Lieu et date : ___Pessac, 14/09/2025________________________________

### Ä Je soussigné (e) monsieur : TARIS Thierry

### Ä Atteste en qualité de : Directeur de Filière, Tuteur de stage tél :__________________________________

### : dénomination social: ENSEIRB Adresse

Ä Pour le compte de | l’organisme de formation
autre | Pays

### Ä Que (nom de l’étudiant (e)) : _________________________________________________________

Ä A (sélectionner la fonction) | - été stagiaire (convention de stage)

### - été employé(e) (contrat de travail) - été bénévole - suivi une formation (valable que pour les stages à l’étranger - autres (à indiquer) :

### A temps complet Ä Sur la période du _____________________au ________________________ Soit _______semaines

## SIGNATURE ET CACHET OBLIGATOIRE DE L’ENTREPRISE OU DE L’ORGANISME

## SIGNATURE DE L’ELEVE

(certifie exactes les informations ci-dessus)


Le responsable des stages ainsi que le directeur des études se réservent le droit de vérifier ces informations Eric.astien@bordeaux-inp.fr (responsable stage 1A)

# BINET Mattéo

02/06/2025 | 27/06/2025 | 4

### 1 avenue du Dr Albert Schweitzer

B.P. 99

### 33402 Talence Cedex France

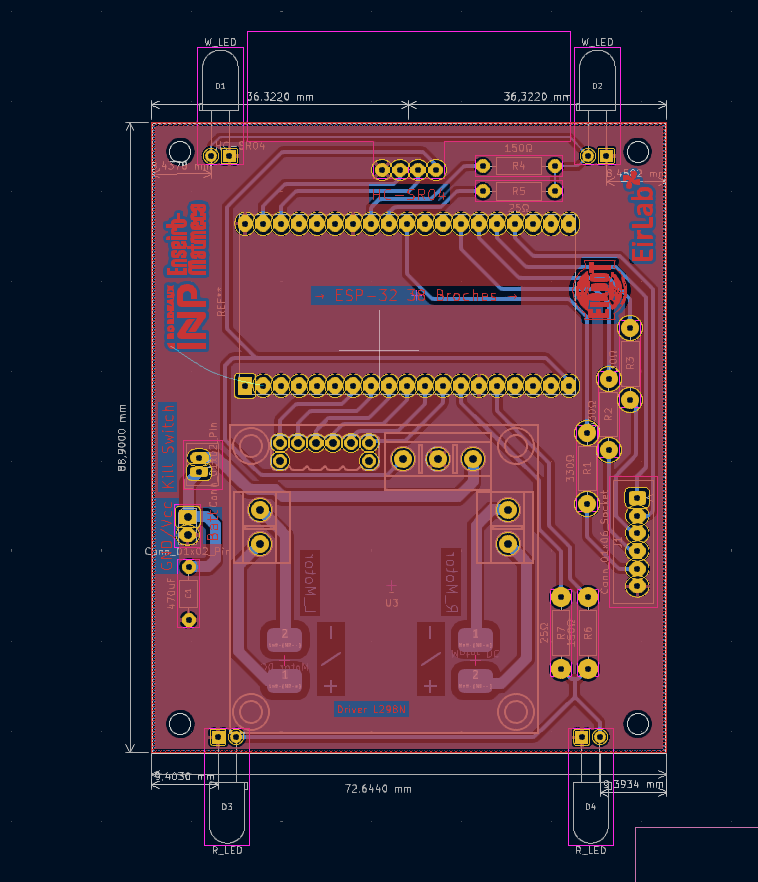
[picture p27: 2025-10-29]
Images/Layout.png

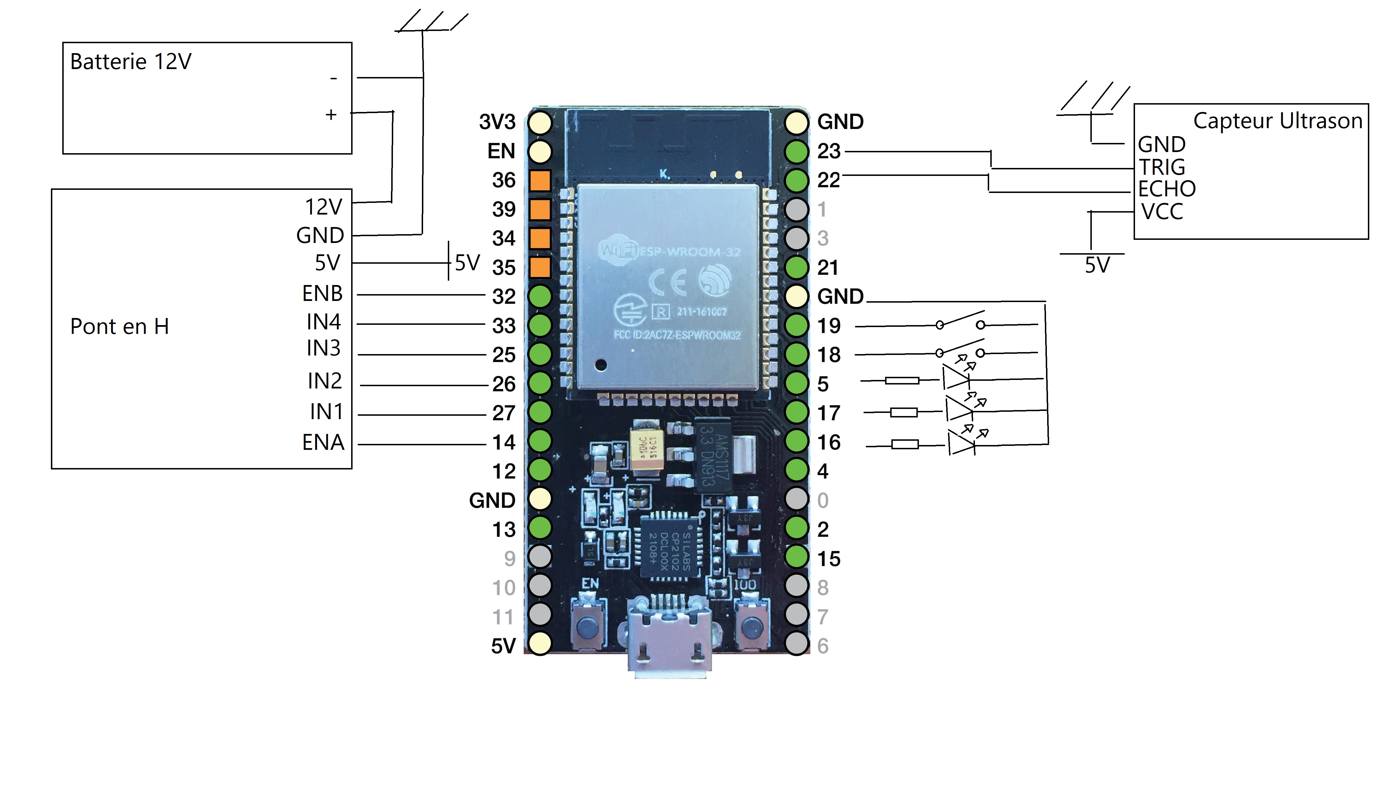
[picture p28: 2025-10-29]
Images/schéma électrique.jpg

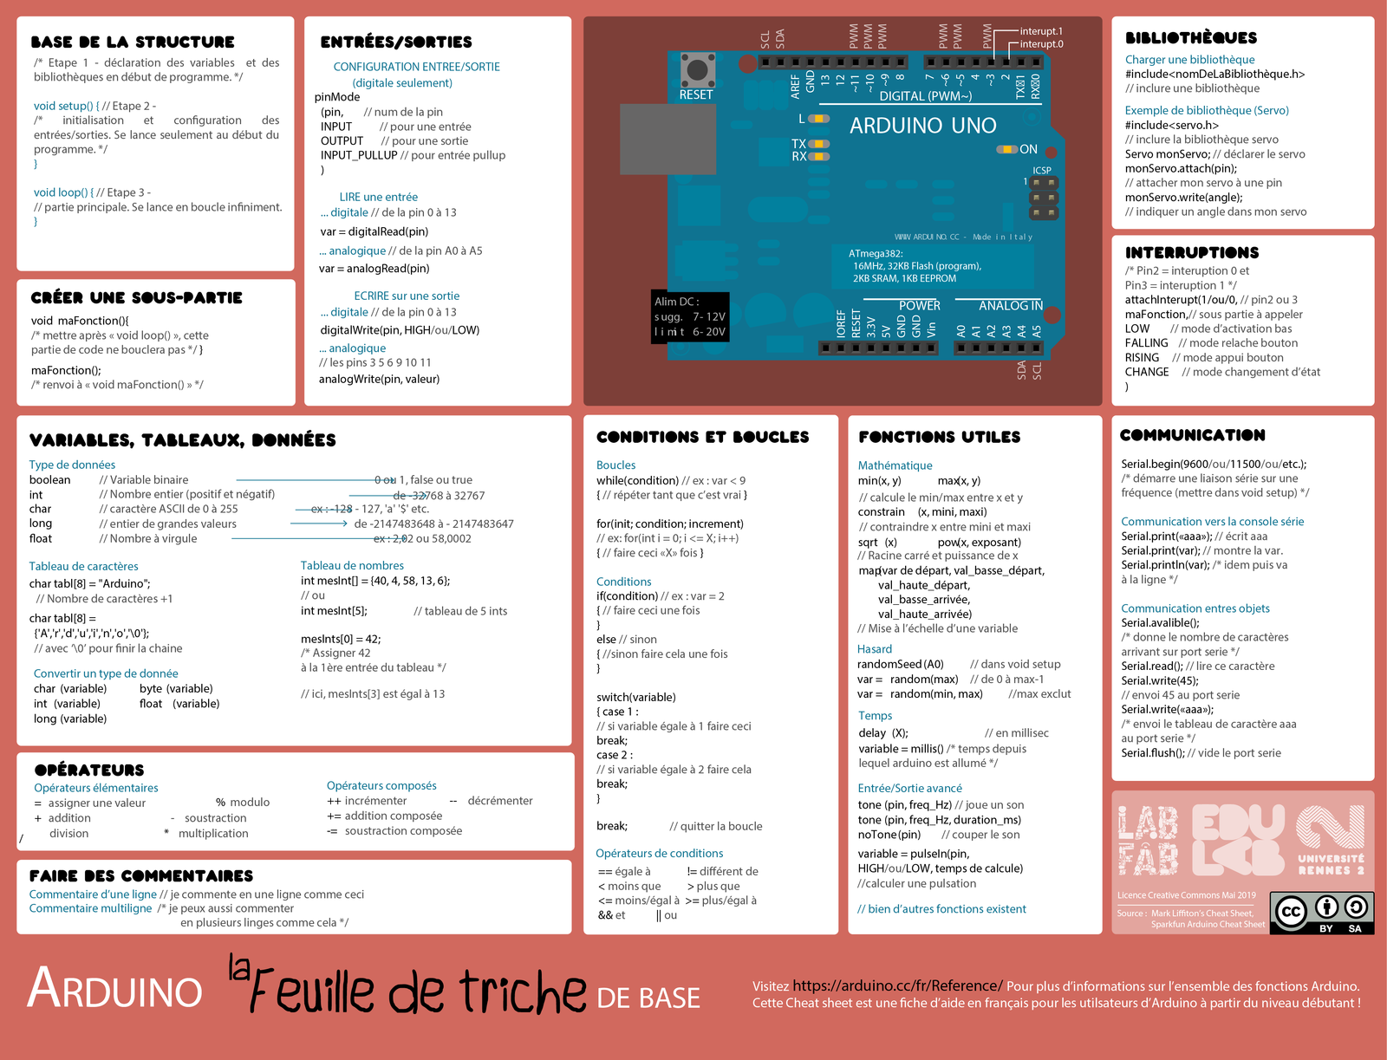
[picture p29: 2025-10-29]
Datasheets/cheatsheet_arduino.png

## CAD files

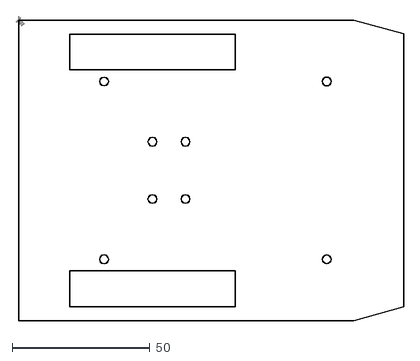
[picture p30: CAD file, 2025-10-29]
Meca/DXF_SVG/plaque_bas.DXF
140.5 x 110.3

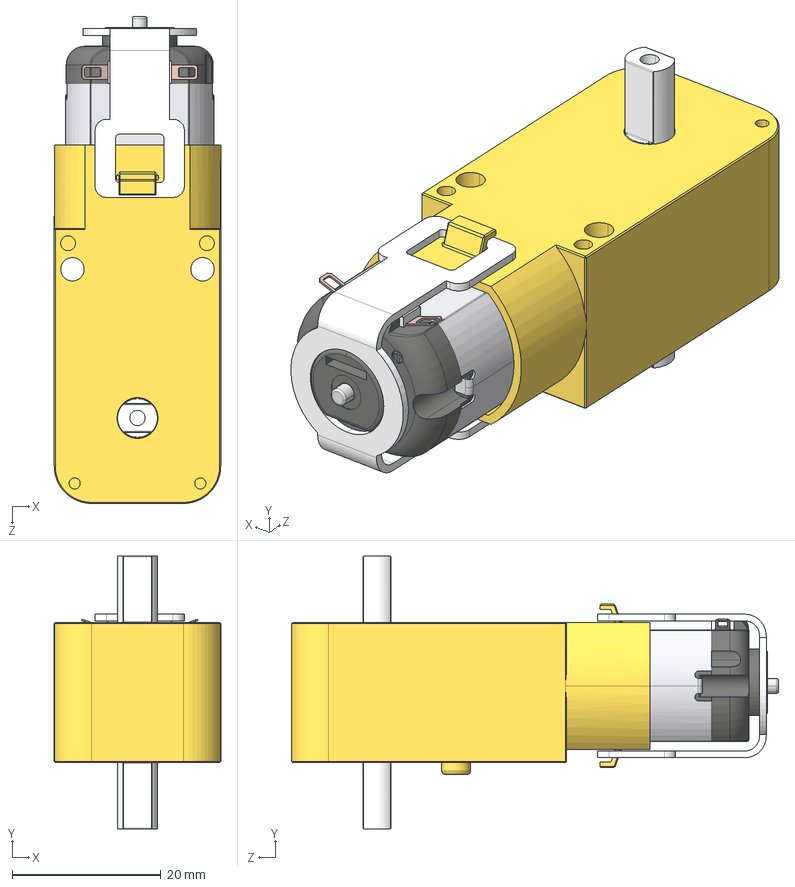
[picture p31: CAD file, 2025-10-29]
Meca/STL_STEP/Mini Gear DC Motor 6 V Yellow.STEP
22.4 x 36.7 x 65.5 mm
dc motor.stp
Nody
Axe
Belt

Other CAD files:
Meca/PCB_shield/PinSocket_1x02_P2.54mm_Vertical_2.SLDASM
Meca/PCB_shield/LED_D5.0mm_Horizontal_O6.35mm_Z3.0mm_2.SLDASM
Meca/PCB_shield/HC-04HC-04_2.SLDASM
Meca/PCB_shield/PinSocket_1x03_P2.54mm_Vertical_2.SLDASM
Meca/PCB_shield/JST_XH_B6B-XH-A_1x06_P2.50mm_Vertical_2.SLDASM
Meca/PCB_shield/ESP32Wroom_2.SLDASM
Meca/PCB_shield/PinSocket_1x04_P2.54mm_Vertical_2.SLDASM
Meca/PCB_shield/JST_PH_B2B-PH-K_1x02_P2.00mm_Vertical_2.SLDASM
Meca/PCB_shield/PinHeader_1x02_P2.54mm_Vertical_2.SLDASM
Meca/PCB_shield/C_Axial_L3.8mm_D2.6mm_P7.50mm_Horizontal_2.SLDASM
Meca/PCB_shield/PinSocket_1x19_P2.54mm_Vertical_2.SLDASM
Meca/PCB_shield/L298N Motor Driver_2.SLDASM
Meca/PCB_shield/PinSocket_1x05_P2.54mm_Vertical_2.SLDASM
Meca/PCB_shield/R_Axial_DIN0207_L6.3mm_D2.5mm_P10.16mm_Horizontal_2.SLDASM
Meca/Mirrorcoque côté.SLDPRT
Meca/PCB_shield/Shield_pad_269_1.SLDPRT
Meca/L298N Motor Driver.SLDPRT
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

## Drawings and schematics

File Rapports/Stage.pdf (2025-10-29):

# Architecture des processeurs II : Etude pratique

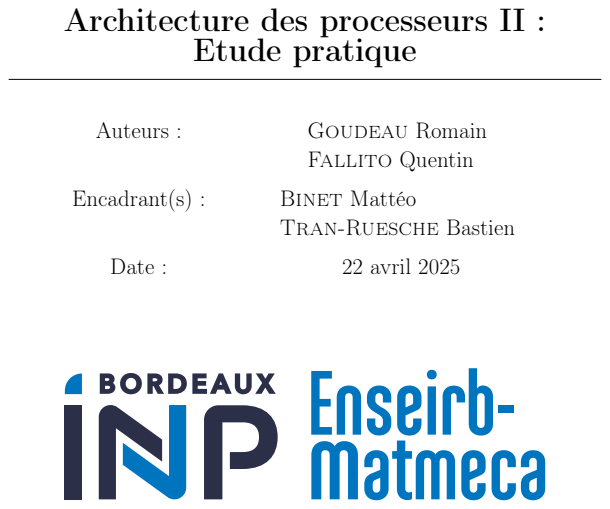
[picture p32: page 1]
Auteurs :; Goudeau Romain; Fallito Quentin; Encadrant(s) :; Binet Mattéo; Date :; 22 avril 2025

Tran-Ruesche Bastien

L’objectif de ce stage est de réaliser un petit robot différentiel commandable en deux modes :

— autonome, avec une trajectoire de déplacement préétablie.

— via appli Bluetooth, pour le piloter en temps réel.

Les principales parties qui composent cet atelier :
— la conception/assemblage d’un robot (modélisation 3d/découpe laser) [≈ 2h]

— une petite partie soudure/électronique avec l’utilisation des postes à souder sur des PCB préparé à l’avance pour voire les parties elec importante (cartes pré routées, connectique à faire) [≈ 1h]

— partie numérique avec le développement de fonctions simple pour comprendre comment communiquer avec les différentes parties du robot (partie Bluetooth cachée, concentration sur la commande des moteurs) [≈ 2h]

Le travail du stagiaire avant l’atelier sera :

— de préparer une structure mécanique de robot suffisamment simple pour que la modélisation soit réalisables facilement par des novices (et face un usage maximal de la laser pour aller plus vite).

— de concevoir une carte d’interconnexion pouvant accueillir les éléments basique d’un robot pour comprendre comment les signaux sont acheminés d’un endroit à l’autre du robot et pouvant être utilisé par des novices.

— de préprogrammé un robot tout en gardant des parties faisables par des novices.

Quentin Fallito | 1/1 | Goudeau Romain

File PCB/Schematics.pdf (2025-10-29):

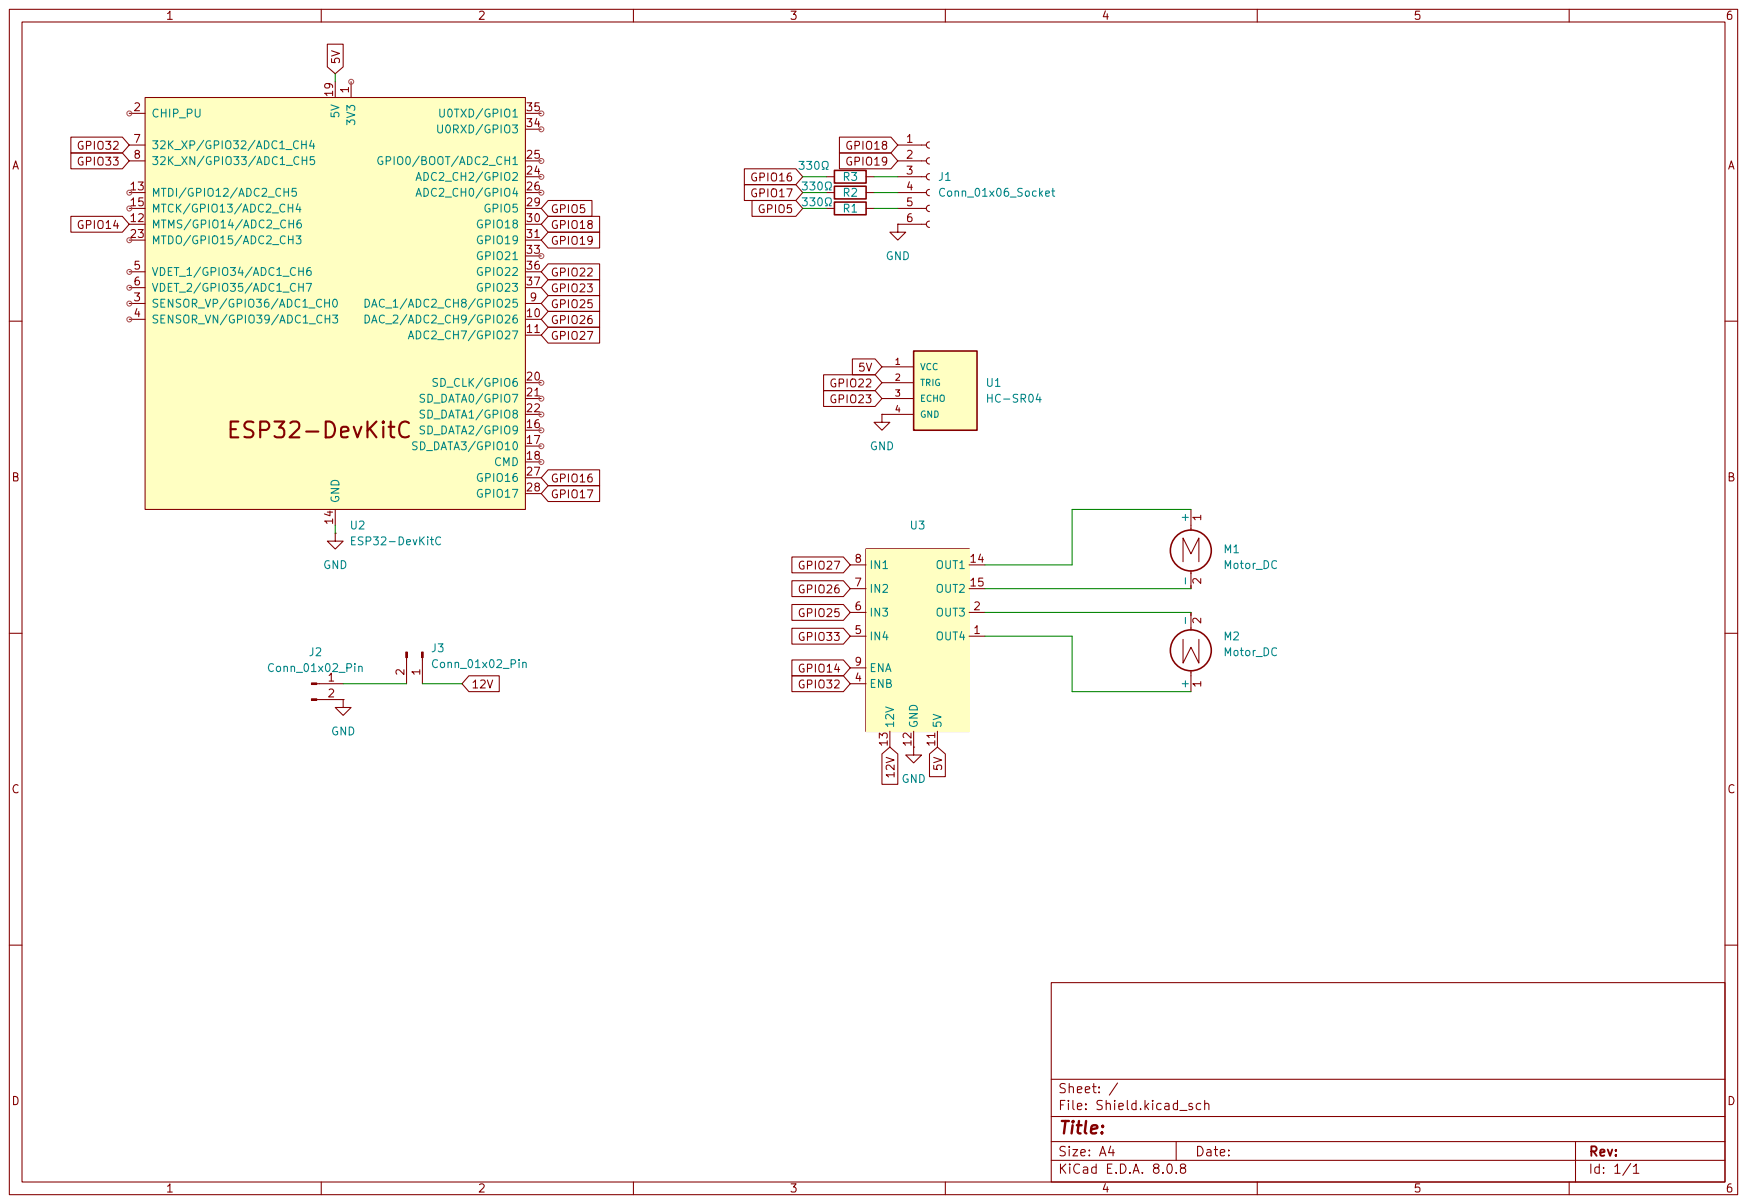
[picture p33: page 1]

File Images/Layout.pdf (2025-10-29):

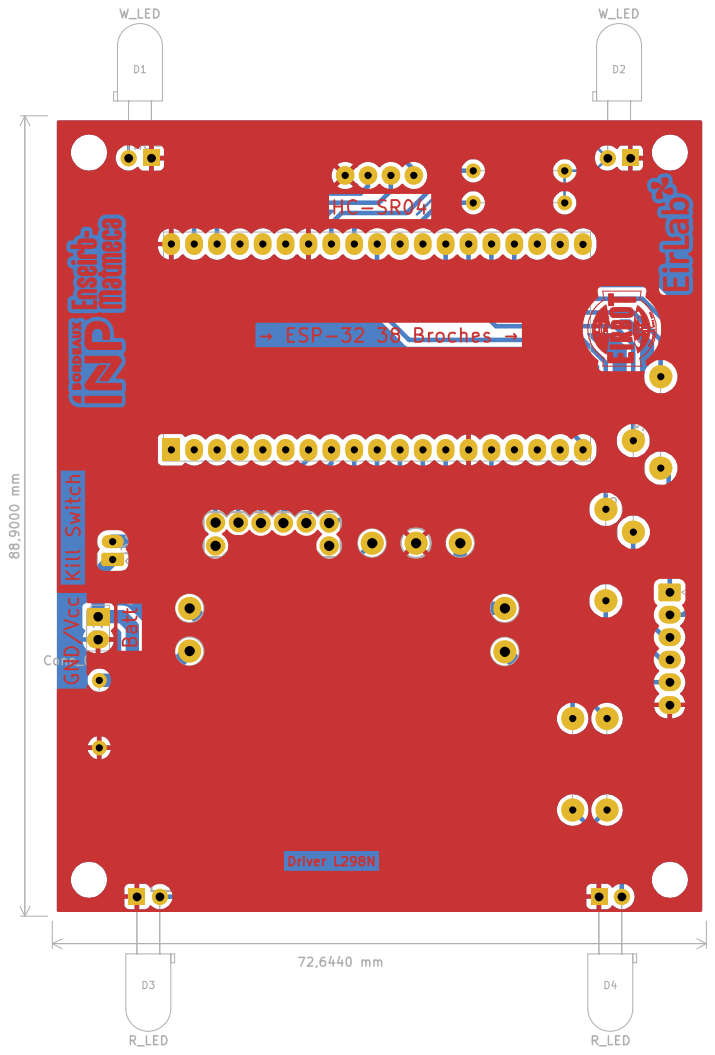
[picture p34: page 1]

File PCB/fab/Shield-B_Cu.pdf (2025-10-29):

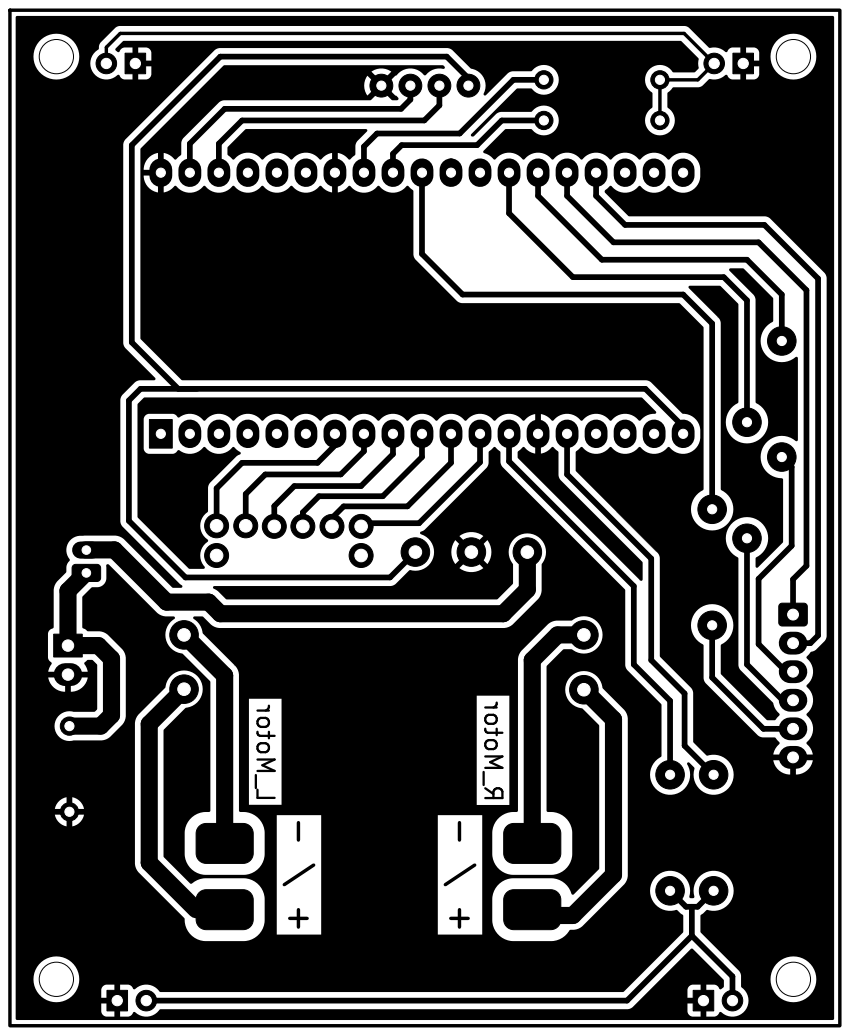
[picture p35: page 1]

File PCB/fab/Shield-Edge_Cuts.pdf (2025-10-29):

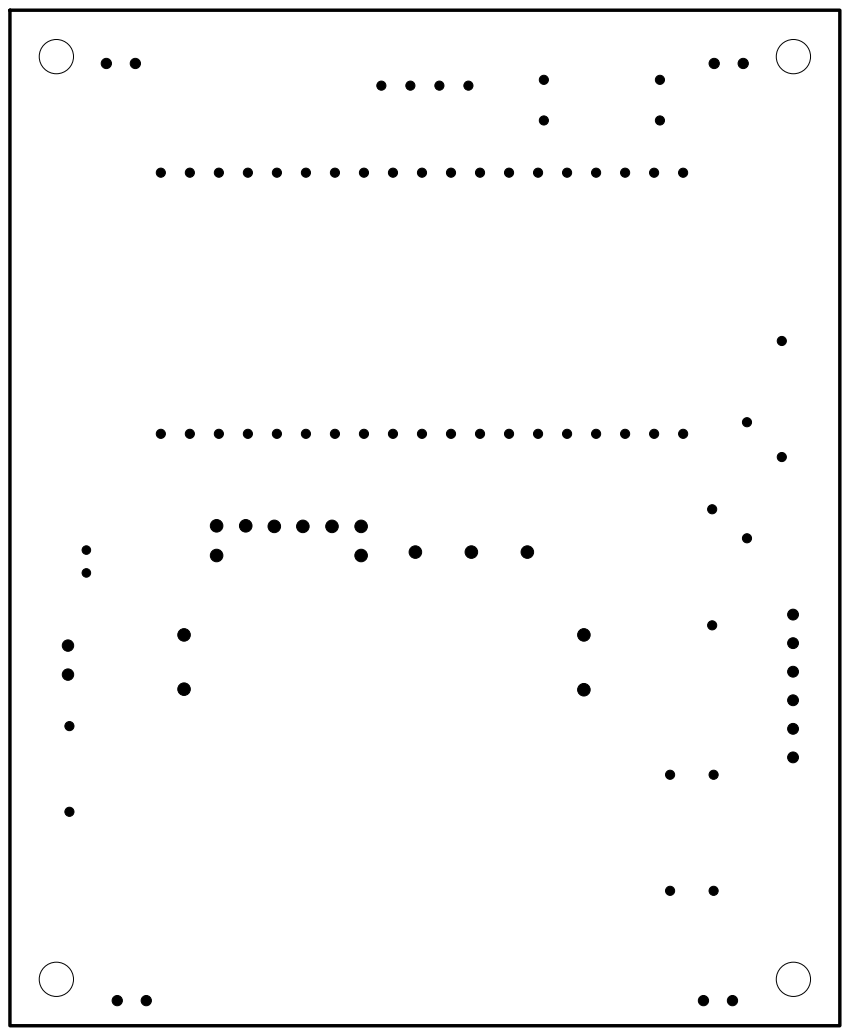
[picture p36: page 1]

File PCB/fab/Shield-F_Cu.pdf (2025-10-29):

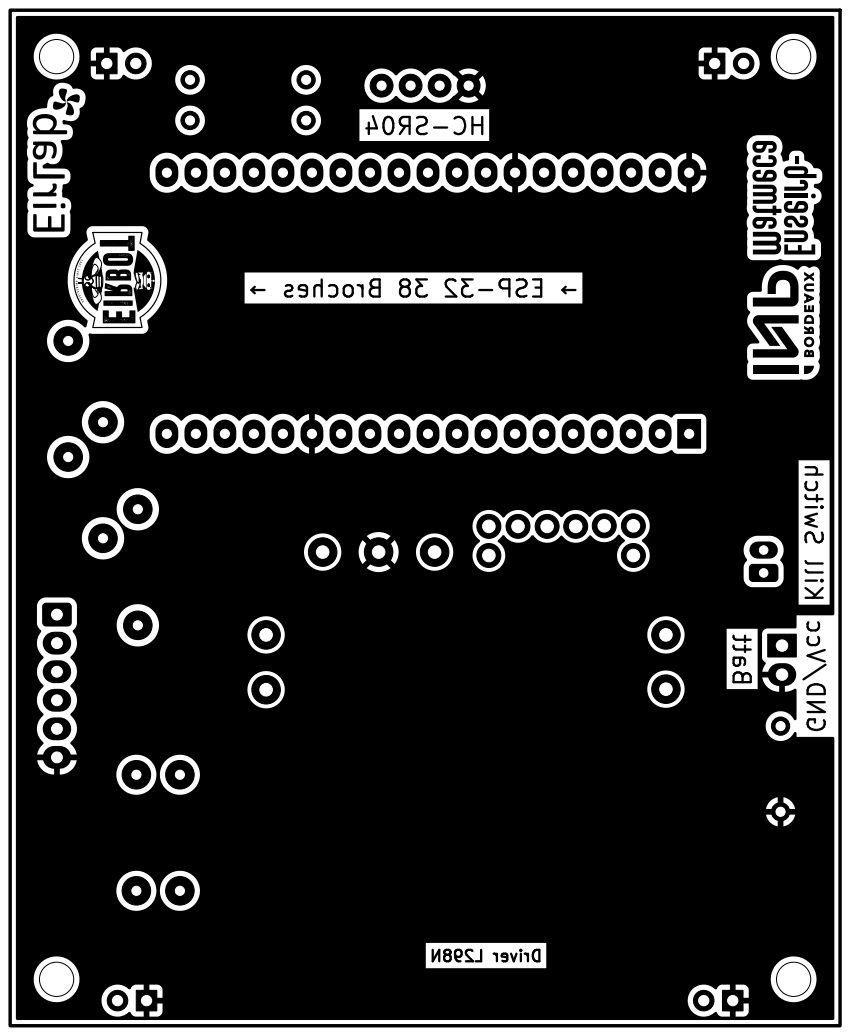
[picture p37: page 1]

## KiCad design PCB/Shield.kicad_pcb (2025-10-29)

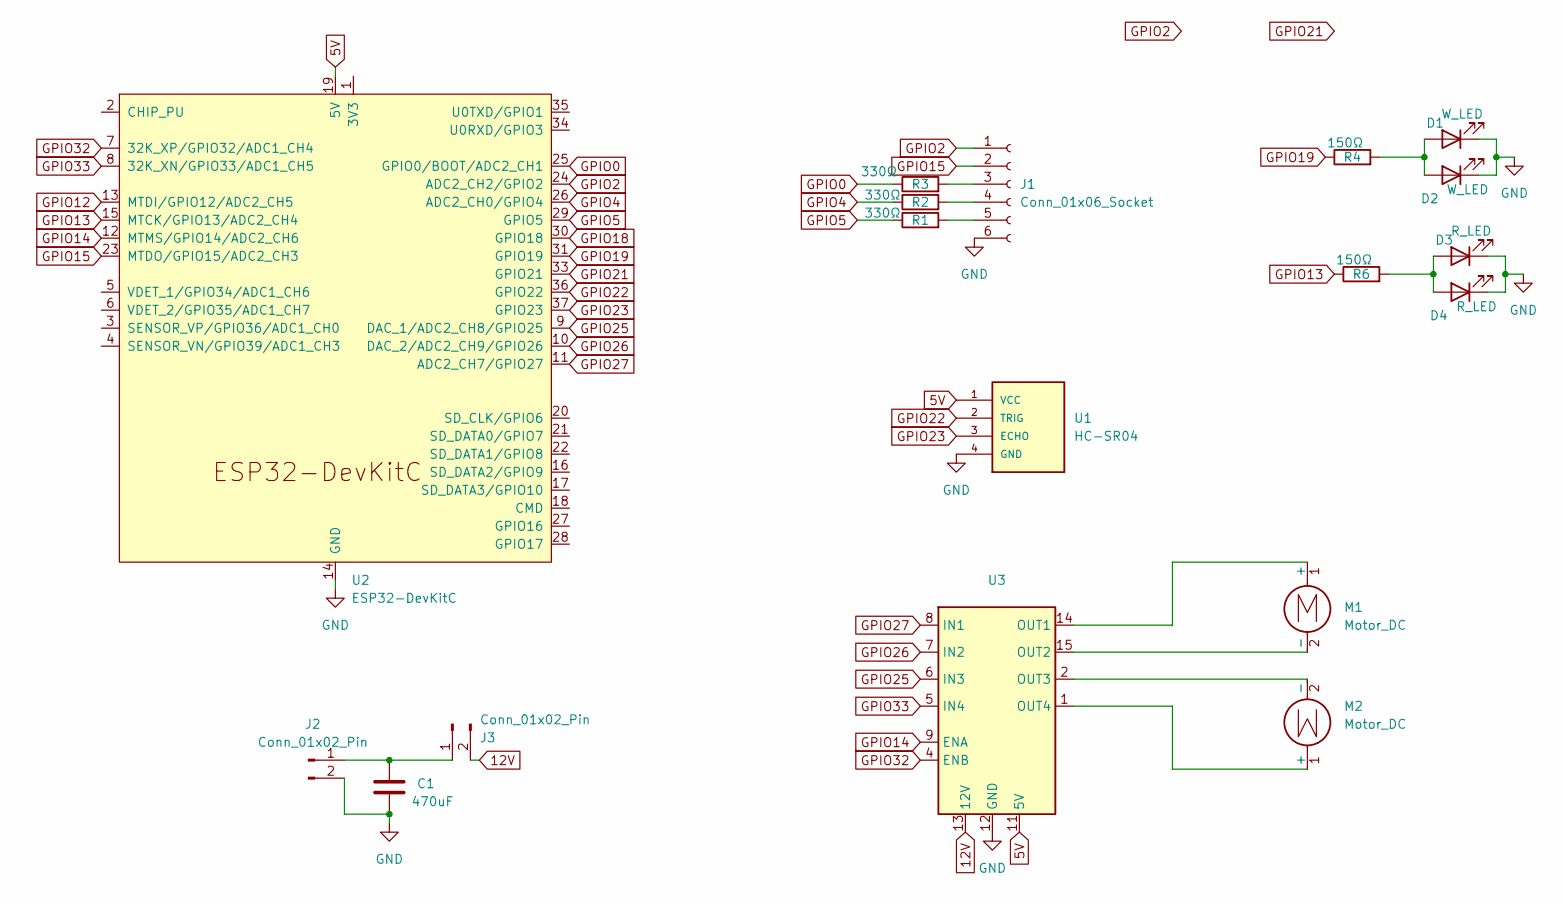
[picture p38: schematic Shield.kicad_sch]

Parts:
C1: 470uF; C_Axial_L3.8mm_D2.6mm_P7.50mm_Horizontal
D1, D2: W_LED; LED_D5.0mm_Horizontal_O6.35mm_Z3.0mm
D3, D4: R_LED; LED_D5.0mm_Horizontal_O6.35mm_Z3.0mm
J1: Conn_01x06_Socket; JST_XH_B6B-XH-A_1x06_P2.50mm_Vertical
J2: Conn_01x02_Pin; PinHeader_1x02_P2.54mm_Vertical
J3: Conn_01x02_Pin; JST_PH_B2B-PH-K_1x02_P2.00mm_Vertical
M1, M2: Motor_DC; Pad_Motor_DC_CMS
R1, R2, R3: 330Ω; R_Axial_DIN0207_L6.3mm_D2.5mm_P10.16mm_Horizontal
R4, R6: 150Ω; R_Axial_DIN0207_L6.3mm_D2.5mm_P10.16mm_Horizontal
U1: HC-SR04; XCVR_HC-SR04
U2: ESP32-DevKitC
U3: Driver_Motor_L298N

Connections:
5V: U1.1 (VCC), U2.19 (5V), U3.11 (5V)
12V: J3.2, U3.13 (12V)
GND: C1.2, D1.1 (K), D2.1 (K), D3.1 (K), D4.1 (K), J1.6, J2.2, U1.4 (GND), U2.14 (GND), U2.32 (GND), U2.38 (GND), U3.12 (GND)
GPIO0: R3.1, U2.25 (GPIO0/BOOT/ADC2_CH1)
GPIO2: J1.1, U2.24 (ADC2_CH2/GPIO2)
GPIO4: R2.1, U2.26 (ADC2_CH0/GPIO4)
GPIO5: R1.1, U2.29 (GPIO5)
GPIO12: U2.13 (MTDI/GPIO12/ADC2_CH5)
GPIO13: R6.1, U2.15 (MTCK/GPIO13/ADC2_CH4)
GPIO14: U2.12 (MTMS/GPIO14/ADC2_CH6), U3.9 (ENA)
GPIO15: J1.2, U2.23 (MTDO/GPIO15/ADC2_CH3)
GPIO18: U2.30 (GPIO18)
GPIO19: R4.1, U2.31 (GPIO19)
GPIO21: U2.33 (GPIO21)
GPIO22: U1.2 (TRIG), U2.36 (GPIO22)
GPIO23: U1.3 (ECHO), U2.37 (GPIO23)
GPIO25: U2.9 (DAC_1/ADC2_CH8/GPIO25), U3.6 (IN3)
GPIO26: U2.10 (DAC_2/ADC2_CH9/GPIO26), U3.7 (IN2)
GPIO27: U2.11 (ADC2_CH7/GPIO27), U3.8 (IN1)
GPIO32: U2.7 (32K_XP/GPIO32/ADC1_CH4), U3.4 (ENB)
GPIO33: U2.8 (32K_XN/GPIO33/ADC1_CH5), U3.5 (IN4)
unnamed: D1.2 (A), D2.2 (A), R4.2
unnamed: D3.2 (A), D4.2 (A), R6.2
unnamed: J1.3, R3.2
unnamed: J1.4, R2.2
unnamed: J1.5, R1.2
unnamed: C1.1, J2.1, J3.1
unnamed: M1.1 (+), U3.14 (OUT1)
unnamed: M1.2 (-), U3.15 (OUT2)
unnamed: M2.1 (+), U3.1 (OUT4)
unnamed: M2.2 (-), U3.2 (OUT3)

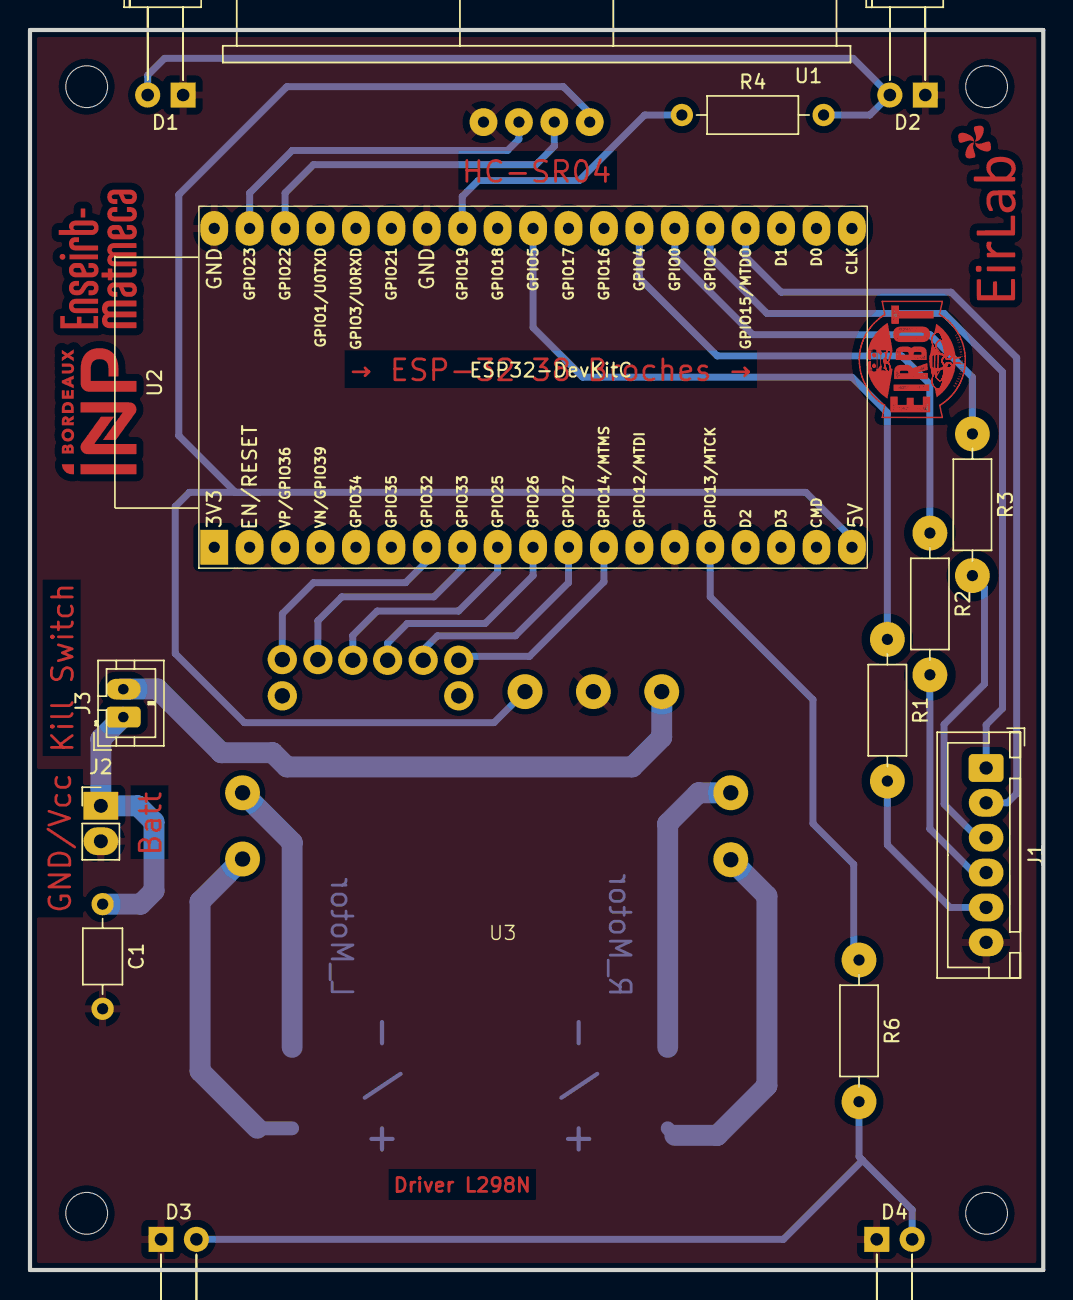
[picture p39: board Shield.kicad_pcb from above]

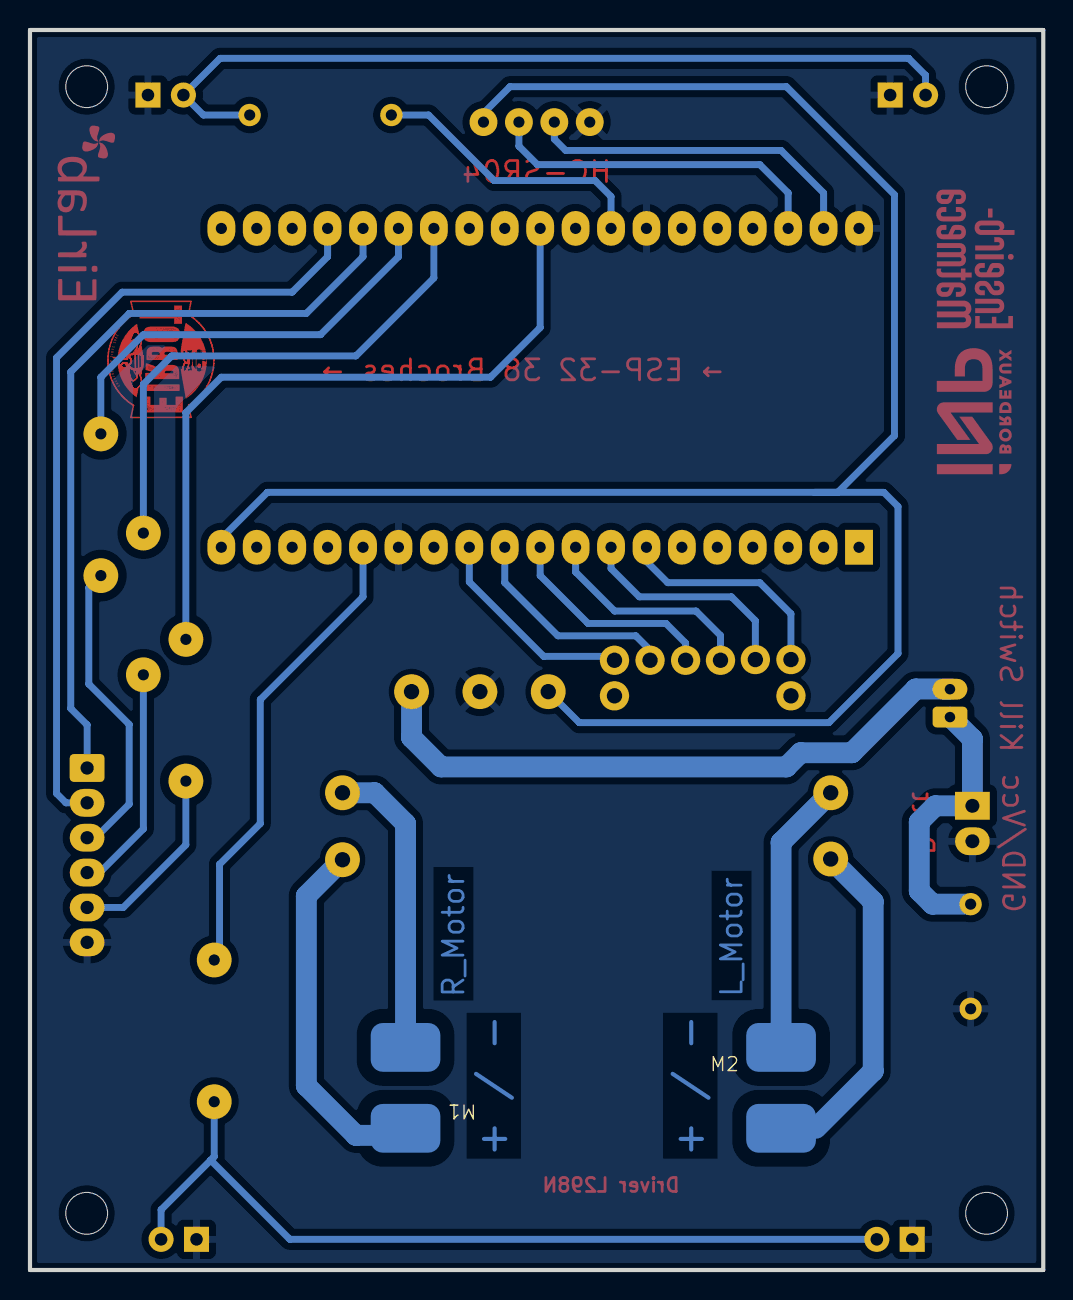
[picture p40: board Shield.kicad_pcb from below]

Board: 2 copper layers, 72.6 x 88.9 mm, 18 parts (2 on the bottom side), 28 nets.

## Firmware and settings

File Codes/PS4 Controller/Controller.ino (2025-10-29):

// Copyright 2021 - 2023, Ricardo Quesada
// SPDX-License-Identifier: Apache 2.0 or LGPL-2.1-or-later

/*
 * This example shows how to use the Controller API.
 *
 * Supported on boards with NINA W10x. In particular, these boards:
 *  - Arduino MKR WiFi 1010,
 *  - UNO WiFi Rev.2,
 *  - Nano RP2040 Connect,
 *  - Nano 33 IoT,
 *  - Arduino MKR Vidor 4000
 */
#include <Bluepad32.h>
#include "pami_lib.h"

ControllerPtr myControllers[BP32_MAX_CONTROLLERS];

// Arduino setup function. Runs in CPU 1
void setup() {
  // Initialize serial
  Serial.begin(115200);
  beginPami();
  while (!Serial) {
    // Wait for serial port to connect.
    // You don't have to do this in your game. This is only for debugging
    // purposes, so that you can see the output in the serial console.
    ;
  }

  String fv = BP32.firmwareVersion();
  Serial.print("Firmware version installed: ");
  Serial.println(fv);

  // To get the BD Address (MAC address) call:
  const uint8_t* addr = BP32.localBdAddress();
  Serial.print("BD Address: ");
  for (int i = 0; i < 6; i++) {
    Serial.print(addr[i], HEX);
    if (i < 5)
      Serial.print(":");
    else
      Serial.println();
  }

  // BP32.pinMode(27, OUTPUT);
  // BP32.digitalWrite(27, 0);

  // This call is mandatory. It sets up Bluepad32 and creates the callbacks.
  BP32.setup(&onConnectedController, &onDisconnectedController);

  // "forgetBluetoothKeys()" should be called when the user performs
  // a "device factory reset", or similar.
  // Calling "forgetBluetoothKeys" in setup() just as an example.
  // Forgetting Bluetooth keys prevents "paired" gamepads to reconnect.
  // But it might also fix some connection / re-connection issues.
  BP32.forgetBluetoothKeys();
}

// This callback gets called any time a new gamepad is connected.
// Up to 4 gamepads can be connected at the same time.
void onConnectedController(ControllerPtr ctl) {
  bool foundEmptySlot = false;
  for (int i = 0; i < BP32_MAX_GAMEPADS; i++) {
    if (myControllers[i] == nullptr) {
      Serial.print("CALLBACK: Controller is connected, index=");
      Serial.println(i);
      myControllers[i] = ctl;
      foundEmptySlot = true;

      // Optional, once the gamepad is connected, request further info about the
      // gamepad.
      ControllerProperties properties = ctl->getProperties();
      char buf[80];
      sprintf(buf,
              "BTAddr: %02x:%02x:%02x:%02x:%02x:%02x, VID/PID: %04x:%04x, "
              "flags: 0x%02x",
              properties.btaddr[0], properties.btaddr[1], properties.btaddr[2],
              properties.btaddr[3], properties.btaddr[4], properties.btaddr[5],
              properties.vendor_id, properties.product_id, properties.flags);
      Serial.println(buf);
      break;
    }
  }
  if (!foundEmptySlot) {
    Serial.println(
        "CALLBACK: Controller connected, but could not found empty slot");
  }
}

void onDisconnectedController(ControllerPtr ctl) {
  bool foundGamepad = false;

  for (int i = 0; i < BP32_MAX_GAMEPADS; i++) {
    if (myControllers[i] == ctl) {
      Serial.print("CALLBACK: Controller is disconnected from index=");
      Serial.println(i);
      myControllers[i] = nullptr;
      foundGamepad = true;
      break;
    }
  }

  if (!foundGamepad) {
    Serial.println(
        "CALLBACK: Controller disconnected, but not found in myControllers");
  }
}

void processGamepad(ControllerPtr gamepad) {
  // There are different ways to query whether a button is pressed.
  // By query each button individually:
  //  a(), b(), x(), y(), l1(), etc...
  float speed = (float)gamepad->throttle();
  if(speed > 40) speed /= 1023.;
  else{
    speed = (float)gamepad->brake() ;
    if(speed > 40) speed /= -1023.;
    else speed = 0;
  }
  avancer(speed, (float)gamepad->axisX() / 512.);
  if(gamepad->dpad() & DPAD_LEFT) trim_left();
  if(gamepad->dpad() & DPAD_RIGHT) trim_right();
  

  // Another way to query the buttons, is by calling buttons(), or
  // miscButtons() which return a bitmask.
  // Some gamepads also have DPAD, axis and more.
  // char buf[256];
  // snprintf(buf, sizeof(buf) - 1,
  //          "idx=%d, dpad: 0x%02x, buttons: 0x%04x, "
  //          "axis L: %4li, %4li, axis R: %4li, %4li, "
  //          "brake: %4ld, throttle: %4li, misc: 0x%02x, "
  //          "gyro x:%6d y:%6d z:%6d, accel x:%6d y:%6d z:%6d, "
  //          "battery: %d",
  //          gamepad->index(),        // Gamepad Index
  //          gamepad->dpad(),         // DPad
  //          gamepad->buttons(),      // bitmask of pressed buttons
  //          gamepad->axisX(),        // (-511 - 512) left X Axis
  //          gamepad->axisY(),        // (-511 - 512) left Y axis
  //          gamepad->axisRX(),       // (-511 - 512) right X axis
  //          gamepad->axisRY(),       // (-511 - 512) right Y axis
  //          gamepad->brake(),        // (0 - 1023): brake button
  //          gamepad->throttle(),     // (0 - 1023): throttle (AKA gas) button
  //          gamepad->miscButtons(),  // bitmask of pressed "misc" buttons
  //          gamepad->gyroX(),        // Gyro X
  //          gamepad->gyroY(),        // Gyro Y
  //          gamepad->gyroZ(),        // Gyro Z
  //          gamepad->accelX(),       // Accelerometer X
  //          gamepad->accelY(),       // Accelerometer Y
  //          gamepad->accelZ(),       // Accelerometer Z
  //          gamepad->battery()       // 0=Unknown, 1=empty, 255=full
  // );
  // Serial.println(buf);

  // You can query the axis and other properties as well. See
  // Controller.h For all the available functions.
}

void processMouse(ControllerPtr mouse) {
  char buf[160];
  sprintf(buf,
          "idx=%d, deltaX:%4li, deltaY:%4li, buttons: 0x%04x, misc: 0x%02x, "
          "scrollWheel: %d, battery=%d",
          mouse->index(),        // Controller Index
          mouse->deltaX(),       // Mouse delta X
          mouse->deltaY(),       // Mouse delta Y
          mouse->buttons(),      // bitmask of pressed buttons
          mouse->miscButtons(),  // bitmask of pressed "misc" buttons
          mouse->scrollWheel(),  // Direction: 1=up, -1=down, 0=no movement
          mouse->battery()       // 0=Unk, 1=Empty, 255=full
  );
  Serial.println(buf);
}

void processBalanceBoard(ControllerPtr balance) {
  char buf[160];
  sprintf(buf,
          "idx=%d, tl:%4i, tr:%4i, bl: %4i, br: %4i, temperature=%d, "
          "battery=%d",
          balance->index(),  // Controller Index
          balance->topLeft(), balance->topRight(), balance->bottomLeft(),
          balance->bottomRight(), balance->temperature(),
          balance->battery()  // 0=Unk, 1=Empty, 255=full
  );
  Serial.println(buf);
}

// Arduino loop function. Runs in CPU 1
void loop() {
  // This call fetches all the controller info from the NINA (ESP32) module.
  // Call this function in your main loop.
  // The controllers' pointer (the ones received in the callbacks) gets updated
  // automatically.
  BP32.update();

  // It is safe to always do this before using the controller API.
  // This guarantees that the controller is valid and connected.
  for (int i = 0; i < BP32_MAX_CONTROLLERS; i++) {
    ControllerPtr myController = myControllers[i];

    if (myController && myController->isConnected()) {
      if (myController->isGamepad()){
        processGamepad(myController);
        digitalWrite(LED_VERTE_PIN, HIGH);
      }
      else if (myController->isMouse())
        processMouse(myController);
      else if (myController->isBalanceBoard())
        processBalanceBoard(myController);
    }
  }
  delay(150);
}

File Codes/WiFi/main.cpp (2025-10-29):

#include <Arduino.h>
#include "pami_lib.h"



void setup()
{

  pinMode(MODE_SWITCH_PIN, INPUT_PULLUP);
  Serial.begin(115200);
  beginPami();

}

void loop()
{
  remote_control();
  // 🤖 Mode automatique : comportement intelligent
  if (digitalRead(MODE_SWITCH_PIN) == MODE_AUTO)
  {
    static enum { AVANCER,
                  STOP,
                  RECULER,
                  TOURNER } etat = AVANCER;
    static unsigned long actionStartTime = 0;
    int distance = mesurerDistance();

    switch (etat)
    {
    case AVANCER:
      avancer();
      if (distance <= 15)
      {
        stop();
        etat = STOP;
        actionStartTime = millis();
        Serial.println("Obstacle détecté — arrêt !");
      }
      break;

    case STOP:
      if (millis() - actionStartTime > 500)
      { // petite pause
        reculer();
        etat = RECULER;
        actionStartTime = millis();
        Serial.println("Recul...");
      }
      break;

    case RECULER:
      if (millis() - actionStartTime > 400)
      {           // recule 400ms
        droite(); // petite rotation droite
        etat = TOURNER;
        actionStartTime = millis();
        Serial.println("Rotation à droite...");
      }
      break;

    case TOURNER:
      if (millis() - actionStartTime > 400)
      { // tourne ≈ 45°
        etat = AVANCER;
        Serial.println("Reprise de l'avance");
      }
      break;
    }
  }
}

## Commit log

2025-10-29 Ajout ./Meca
    [C_Axial_L3.8mm_D2.6mm_P7.50mm_Horizontal_2.SLDASM, C_Axial_L38mm_D26mm_P750mm_Horizontal_2.SLDPRT, ESP32Wroom_2.SLDASM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]
2025-10-29 Ajout fichier du PCB_shield
    [Shield_PCB_2.SLDPRT, Shield_pad_100_1.SLDPRT, Shield_pad_101_1.SLDPRT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]
